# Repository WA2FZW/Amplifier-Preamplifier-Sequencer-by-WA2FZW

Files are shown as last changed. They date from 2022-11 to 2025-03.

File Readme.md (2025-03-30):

Amplifier/Preamplifier/SDR Switch Sequencer Version 2.0
By: John Price – WA2FZW - March 30, 2025

This is a software controlled sequencer designed to be able
to control two low-noise mast-mounted preamplifiers, linear
amplifiers and SDR switching devices when used with the
Icom IC-9700 on any two of the three bands that radio can
operate on.

The timing of the sequencing is controlled by the software
in an Arduino Nano.

Version 2.0 is an improvement over previous versions in
that the sequencing can be initiated via a DTR or RTS
signal from an optional USB to TTL interface. The
sequencing can also be initiated via an optional footswitch.
This has the advantage of being able to put the radio
into transmit mode after the preamps and amplifiers have
been switched.

The documentation, software and Gerber files to make the
version 1.4 PCBs are still available here. That version
is designed for use with my Yaesu FT-891.

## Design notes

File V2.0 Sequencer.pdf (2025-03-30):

- Page 1 -

## IC-9700 Amplifier/Preamp Sequencer Version 2.0 © John Price – WA2FZW - March, 2025

## Table of Contents

- Page 2 -

- Page 3 -

## Introduction

This document describes a sequencer used to switch one or two linear amplifiers, antenna mounted receive preamplifiers and switch boxes that allow receiving on an SDR when the radio status changes from transmit to receive and vice-versa.

Version 1.0 of the device was specifically designed to work with the Yaesu FT-891. (https://www.yaesu.com/indexVS.cfm?cmd=DisplayProducts&ProdCatID=102&encProdID=DF4DB262968932E999EAF928B5B6A1A7)

In Version 1.4 I added the capability to key one or the other of two amplifiers, but it only supported one preamp and one SDR switch box. Version 1.5 supports two of everything, but eliminates the transmit inhibit capability used in the unit for the Yaesu FT-891.

Version 1.5 is designed specifically for the Icom IC-9700 (https://www.icomamerica.com/en/products/amateur/hf/9700/default.aspx) on any 2 of the 3 bands it can operate on. In my case, I’m only operating on 2 meters and 70 centimeters and thus you’ll see that the panel labels on my unit reflect that.

Version 2.0 improves the design when being used for the digital modes. By adding an optional USB to TTL converter, (https://modulshop.hu/custom/modulshop/image/data/srattached/32e90db4e053c6b6411c2638c8aaf046_6in2-cp2102.pdf) WSJT-X can be told to use that to initiate the sequence via the RTS (Request to Send) signal instead of CAT (CI-V) control. The sequencer will switch the preamp followed by the amplifier and finally the radio itself; this accomplishes the same thing as the Yaesu’s transmit inhibit did in the original design. You could also use DTR (Data Terminal Ready) to accomplish the same thing.

When operating SSB or CW, you can use an optional footswitch to trigger the sequencer which works like the RTS signal in that the radio will be keyed last.

If neither the USB to TTL converter or footswitch is installed, the sequencer will work like previous versions; triggered by keying the radio’s microphone, transmit button or CAT control. Do not try to operate break-in CW or use VOX control under any circumstances when using the sequencer this way.

- Page 4 -

## The Hardware

Some Assumptions

- If installed, the RTS line on the USB to TTL converter is normally at 5V and goes to ground when RTS is activated.
- The radio has a PTT line (SEND in IC-9700 nomenclature) that goes to ground when the radio is put into transmit mode either manually or via CAT control.
- The sequencer can key the radio by grounding its PTT (SEND) line (indirectly via the TX_KEY GPIO pin and K4) when the sequencer is activated via the RTS line.
- The preamplifiers are put in receive mode by powering them from a +12V source. Removing the +12V power switches them to transmit (bypass) mode (fail-safe operation).
- The SDR switch boxes are switched from receive mode to transmit mode by grounding a PTT input on the switcher. SW4 and SW5 on the schematic are optional switches to ground the PTT line of the SDR switchers to put one or both into permanent transmit (bypass) mode.
- The linear amplifiers are keyed by grounding their keying inputs. Relay contacts are used for this so the amplifier’s keying voltage can be pretty much anything. A SPDT switch (SW6) selects which of the two amplifiers is actually keyed. I used a center-off switch which allows neither amplifier to be keyed.
- This sequencer is designed primarily to be used when running the various digital modes.
- J8 connects to an optional RCA jack which is for a footswitch. The footswitch acts like the RTS signal and provides a fail-safe method of operating for SSB and CW.

The use of the USB to TTL converter is optional. If not used, the digital mode programs can still trigger the sequence via CAT commands as in previous versions of the sequencer. If you don’t use the USB to TTL converter, K5 does not need to be installed.

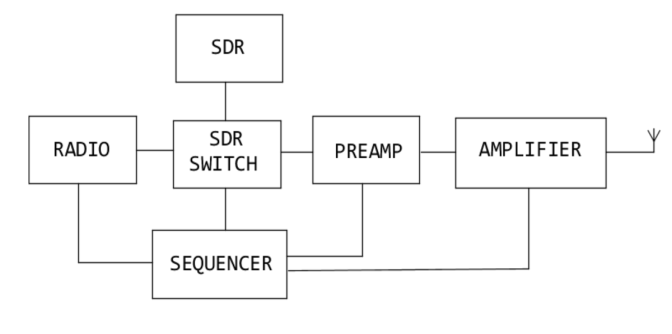
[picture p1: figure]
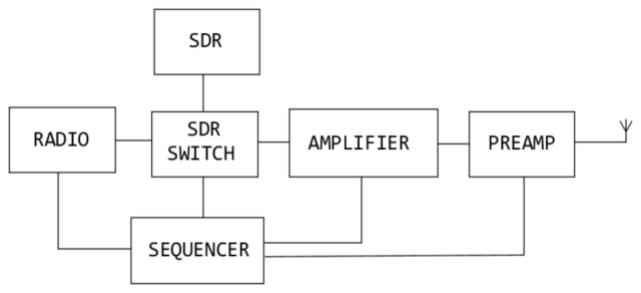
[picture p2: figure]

- Page 5 -

Equipment Configurations

There are two possible configurations one might use when using an external preamplifier, linear amplifier and/or SDR switch:

Configuration 1 | Configuration 2

The primary difference is whether the preamp is ahead of or behind the amplifier. If you have preamplifiers that can handle the output power of the amplifier, it’s better to put them between the antenna and the amplifier and as close to the antennas as possible.

Any of the major components (except the radio and antenna) are optional. If all you have is a radio and an antenna, you can stop reading because you have no need for this sequencer!

Which configuration you have and what specific equipment will determine how to set the various delay values in the software.

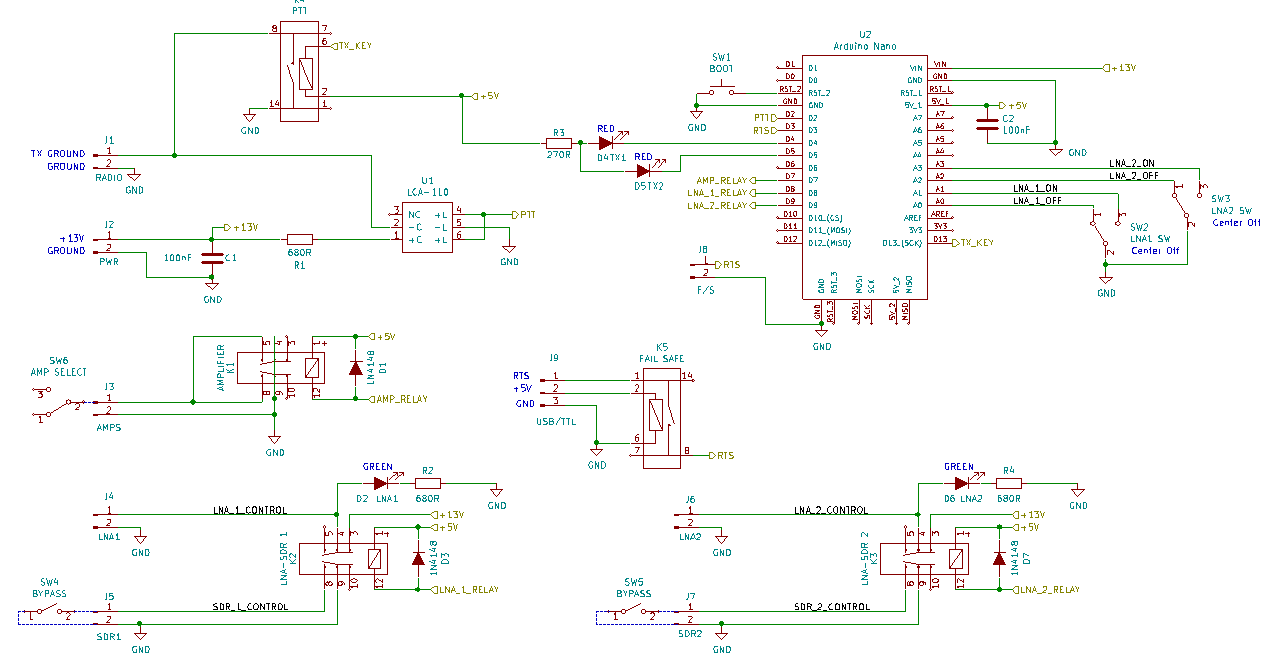
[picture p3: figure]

- Page 6 -

Theory of Operation

Here’s the schematic:

Switches SW4, SW5 and SW6 are optional.

Note that although the schematic shows the +13V power source as being from the radio, I power mine from the same 12V power supply that powers the radio. The IC-9700 is capable of 1 amp from the ACC connector and I would be pushing that limit with the relays in the 2 LNAs and the SDR switchers in my configuration. I ran the original version of the sequencer from the radio’s power when there was only one preamp being switched with no problems.

When the various pieces of equipment are switched between receive and transmit mode is controlled by the software in the Arduino Nano processor. We’ll get to setting the timing later.

In Version 2.0, the receive to transmit sequence can be initiated in three ways. When using WSJT-X (or any of the other digital mode programs), the sequence is initiated via a RTS signal provided from an optional USB to TTL converter. (https://modulshop.hu/custom/modulshop/image/data/srattached/32e90db4e053c6b6411c2638c8aaf046_6in2-cp2102.pdf) The link is for the particular one I used; I suspect there others which will work just as well.

- Page 7 -

When the RTS input goes LOW, the processor immediately switches the preamps and SDRs to the transmit mode via K2 and K3. After LNA_ON_DLY milliseconds, the selected amplifier is keyed via K1. Then after PTT_ON_DELAY milliseconds, the TX_KEY GPIO pin is set to TX_ON which will put the radio itself into transmit mode by activating the radio’s PTT line via K4 on the schematic.

The sequence can also be initiated when the radio’s PTT line goes active; this will be the case when the radio is sent a transmit command via CAT control or the operator keys the microphone. This is indicated by the radio’s PTT input going to ground. That causes a LOW indication on the PTT output of U1 on the schematic.

When the transmit sequence is started via the radio’s PTT line, the process is the same except we do not re-key the radio via the TX_KEY GPIO pin. Be very careful when keying the transmitter manually as it is very easy to destroy the preamp and/or SDR. It is much safer to use the optional footswitch for SSB or CW.

The transmit to receive sequence is also a bit different in Version
2.0. There is the (remote) possibility that while the radio was initially put into the transmit mode via the RTS signal, the operator also manually keyed the radio. The process will be explained in the description of the SetReceive function below.

Preamp Always On or Off Switch Considerations

Two switches (SW4 and SW5) were added in a previous version of the hardware when I started using the IC-9700 for satellite work. When working the satellites, the radio is transmitting on the 70cm band and receiving on 2 meters (or vice-versa). Without the switches, when transmitting on 70cm and listening on 2 meters, the 2 meter preamp would switch off when I transmitted causing me to sometimes no longer be able to hear myself.

Putting the switch for the receive band in the ‘ON’ position cured the problem.

VERY IMPORTANT: Be very careful when switching back to normal operations to put the switch back to the normal operating position or to the ‘OFF’ position. I already fried one rather expensive preamp!

- Page 8 -

When one (or both) of the switches is in the ‘ON’ position the red transmit indicator LED for that band will flash rapidly as an alert when the radio’s PTT is not active. When the PTT goes active, however, both red LEDs will be on continuously.

Also when the switch is in the ‘ON’ position, the SDR switch will be stuck in receive mode. You can put them into permanent transmit mode by powering them off or putting the (optional) SDR Disable switches (SW1 and SW2) into the ‘DISABLE’ position. Of course you won’t be able to receive on the SDR in this mode.

My SDR switcher (https://github.com/WA2FZW/SDR-Splitter-Switcher-by-WA2FZW) also has its own bypass switch.

K5 is a fail-safe relay. I found in testing the initial prototype that when the USB connection to the USB to TTL converter was disconnected, the RTS signal went to a LOW (active) state which caused everything to switch to transmit mode. The same thing would happen when rebooting the PC.

If the 5V output from the USB to TTL converter goes away, K5 disconnects the RTS line from the processor. The Arduino’s internal pullup resistor on GPIO pin D3 keeps the RTS signal showing as inactive. The footswitch (also connected to D3) will continue to be functional.

The Printed Circuit Board

The hardware consists of a printed circuit board (PCB) containing an Arduino Nano (https://www.arduino.cc/en/pmwiki.php?n=Main/ArduinoBoardNano) (or clone) processor, five mechanical relays, (https://www.jameco.com/webapp/wcs/stores/servlet/ProductDisplay?catalogId=10001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) one solid state relay (SSR), a few resistors, a couple of capacitors and several LEDs and switches (mounted externally).

The board can be powered from the radio if it can conveniently provide 12 to 13 volts and enough amperage however one must be careful not to exceed any current limitations the radio might have (1 amp max for the IC-9700). I powered earlier versions of the sequencer (with a single preamp and no SDR switcher) from the radio with no problems but now use a separate power supply (A wall-wart is fine if it doesn’t make RFI). I use the same power supply that powers the radio.

U1 is an LCA-110 solid state relay (SSR) which provides isolation between the radio’s PTT line and the processor. It is required as the normal voltage on the PTT line is more than the 5V that the Arduino pins can handle. I measured a bit over 6V on my IC-9700; it may be higher for other radios.

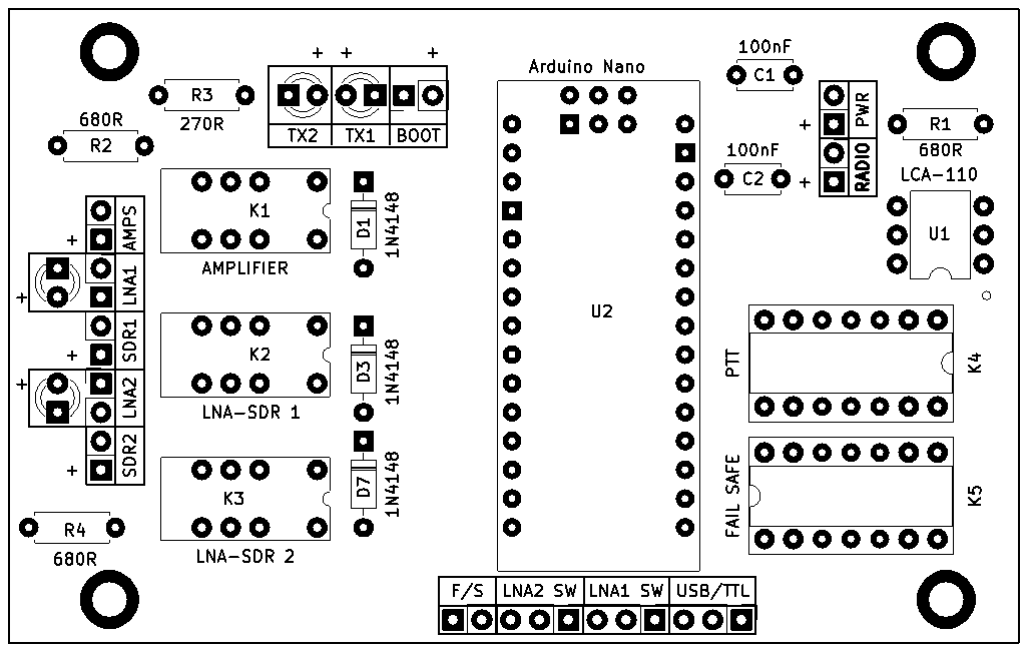
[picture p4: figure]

- Page 9 -

Relay K1 keys the amplifier(s). Relays K2 and K3 provide power to the preamps and ground the PTT inputs on the SDR switches in transmit mode. K4 grounds the radio’s PTT line when the sequence is initiated via the RTS signal

The LEDs indicate when the radio’s PTT line is active (red), and when the preamp is in receive mode (green). The preamp LED is operated by the relay which supplies power to the preamp in receive mode providing a positive indication that power is actually being sent to the preamp (or at least to the connector on the rear panel).

SW4 and SW5 are connected to the PCB. The optional switches to disable the SDRs (SW1 and SW2) are not connected to the PCB, but are simply SPST switches that ground the PTT lines to the SDR switchers. I simply connected them across the RCA jacks for the SDR switchers.

The SPDT switch (SW6) to select which amplifier should be keyed is connected between J3 (AMPS) and the RCA jacks for the amplifier keying lines.

Here’s what the printed circuit board layout looks like:

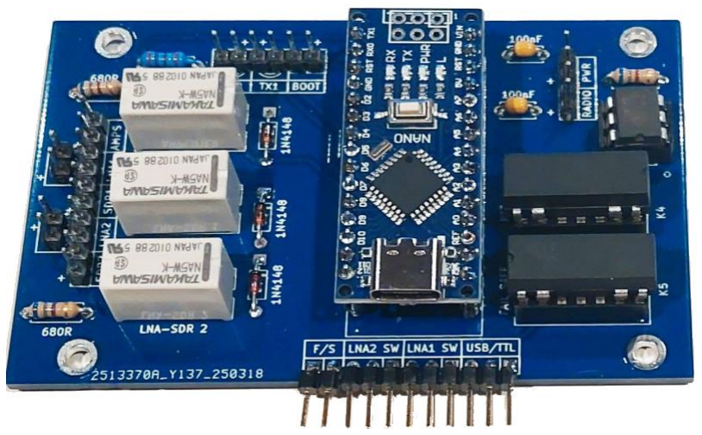
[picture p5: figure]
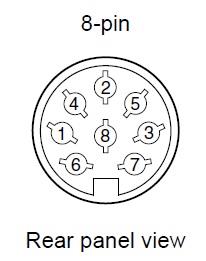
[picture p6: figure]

- Page 10 -

And here’s the assembled circuit board:

Icom IC-9700 Connections

The Icom uses a large size 8 pin DIN connector (ACC) for the external connections:

I have a couple versions of the IC-9700 Basic Operating Manual, (https://www.icomjapan.com/support/manual/2156/) however they all have the same description of the pins on the ACC DIN connector. On the original version for the IC-9700, I cut one end off of a DIN cable and hardwired the cable to the PCB; this time I used a DIN jack on the rear panel of the sequencer. The DIN Cable I used to make the connection came from Amazon. (https://www.amazon.com/dp/B0794WSGN9?ref=ppx_yo2_dt_b_product_details&th=1)

- Page 11 -

The following table gives the pin usage I used to connect the radio to the sequencer (I used an external power source instead of the 13.8V from the radio as it is only capable of supplying 1 amp):

Pin | IC-9700 Nomenclature
2 | Ground
3 | Send (aka PTT)
7 | +13.8V @ 1 Amp

The Icom manual says the SEND line is both an input and an output (I verified this). When the radio is keyed via the microphone’s PTT button, the TRANSMIT button on the front panel or via CI-V control, the SEND line goes LOW.

Putting a LOW on the SEND line will also cause the radio to go into transmit mode.

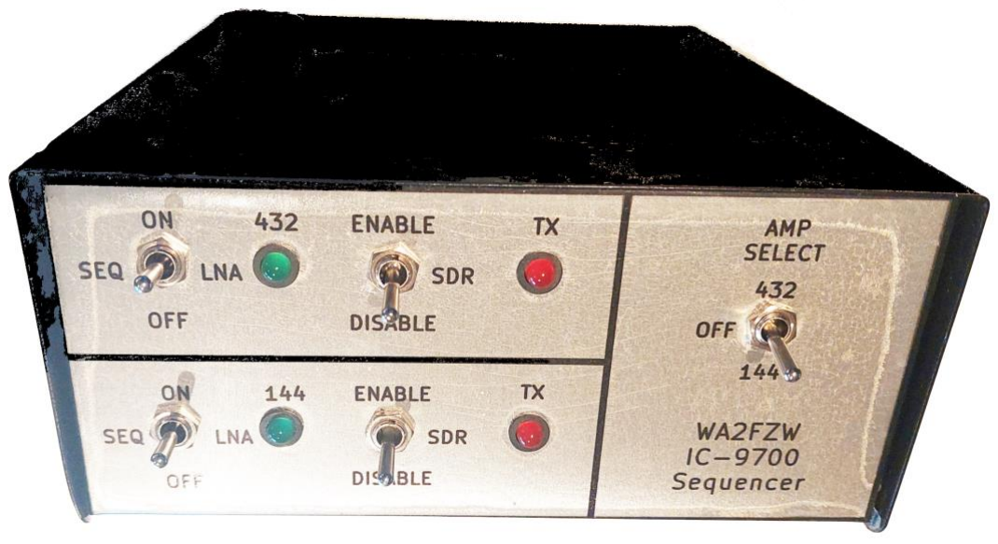
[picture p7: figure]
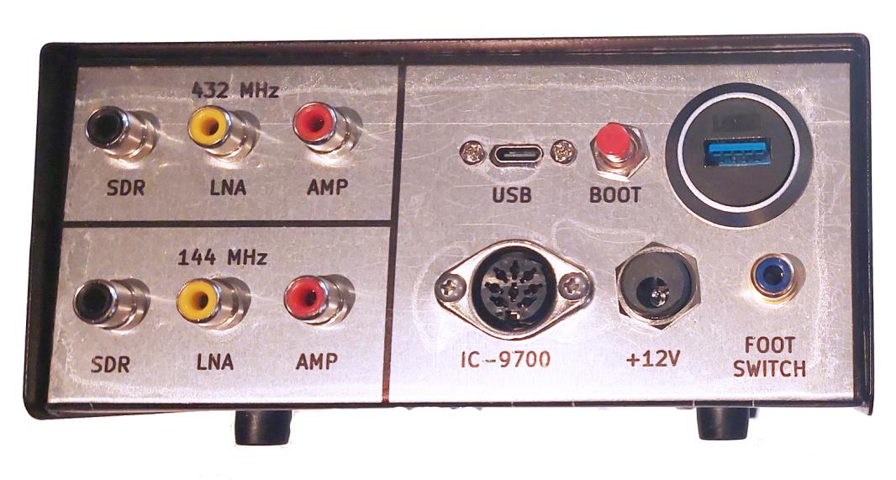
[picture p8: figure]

- Page 12 -

Some Construction Notes

I built the unit into an enclosure from Circuit Specialists. (https://www.circuitspecialists.com/metal-instrument-enclosure-e-3) Here’s what the final assembly looks like (sorry, not the greatest pictures):

- Page 13 -

## The Software

GPIO Pin and Other Symbols Defined

The following are the GPIO pin assignments; for the most part, the symbols used match the net names on the schematic:

PTT | 2 | PTT Indication (interrupt capable)
RTS | 3 | RTS Indication (interrupt capable)
TX1_LED | 4 | Band #1 transmit indicator LED
TX2_LED | 5 | Band #2 transmit indicator LED
AMP_RELAY | 7 | Operates the linear amplifier relay (K2)
LNA1_RELAY 8 | Operates the band #1 preamp/SDR relay (K3)
LNA1_RELAY 9 | Operates the band #2 preamp/SDR relay (K4)
TX_KEY | 13 | Operates K1 to ground the PTT line
LNA1_OFF | A0 | Preamp for band 1 always off when LOW
LNA1_ON | A1 | Preamp for band 1 always on when LOW
LNA2_OFF | A2 | Preamp for band 2 always off when LOW
LNA2_ON | A3 | Preamp for band 2 always on when LOW

The DEBUG symbol can be defined as 0, 1 or 2. When set to 0, no debugging stuff is enabled. Setting DEBUG to 1 causes various status messages to be sent to the Arduino IDE’s serial monitor. Setting the value to 2 also exaggerates the sequence timing values to facilitate monitoring with meters and/or an oscilloscope for testing.

There are several definitions of states for the various GPIO pins to make the pin states more readable, for example:

AMP_ON | LOW | // A LOW on the AMP_RELAY pin keys the linear
AMP_OFF HIGH

There are several global variables:

txState | | Current transmit/receive state
oldTxState | Previous transmit/receive state
rtsState | | Current state of the RTS line
pttState | | Current state of the PTT line
lna_1_ForcedOff true when switch SW2 is in the always off
| | position
lna_1_ForcedOn | true when switch SW2 is in the always on position
lna_2_ForcedOff true when switch SW3 is in the always off
| | position

- Page 14 -
lna_2_ForcedOn | true when switch SW3 is in the always on position
tx_1_LedState | Used in CheckBlink to toggle the LED state
tx_2_LedState | Used in CheckBlink to toggle the LED state

Timing Settings

There are four symbols in the software that define the timing for the sequencer:

LNA_ON_DELAY | 25mS Time between switching the LNA(s) to transmit mode and keying the amplifier
PTT_ON_DELAY | 50ms Time between keying the amplifier and keying the radio when the sequence is initiated via the RTS signal.
PTT_OFF_DELAY | 10mS Used in the SetReceive function when it is determined that the PTT line is active because of K4 being energized.
AMP_OFF_DLY | 50mS Delay between turning the amplifier(s) off and returning the preamp and SDR switch to receive mode.

The values shown are those currently set in the software when the DEBUG level is 0 or 1. The values may be adjusted to suit your needs based on the specifications of your particular equipment and the equipment configuration. There are alternate settings that are used when the DEBUG level is set to 2; I currently have all except PTT_OFF_DELAY set to 3 seconds.

Note, the sequencer is designed primarily for digital mode operations. It can be used for SSB operations using manual PTT (not VOX) and pause slightly between keying the radio and speaking. Using it for CW operation should only be done if the radio is put into transmit manually before operating the CW key; in other words don’t try using break-in modes (I fried a $250 LNA that way)! You can also use a footswitch to trigger the transmit sequence. Using the footswitch is the same as triggering the transmit sequence via the RTS line which will cause the preamps and linear to be switched before the radio.

- Page 15 -

Overall Functionality

The software is pretty trivial. The setup function sets up all the GPIO pins used and sets them to the proper initial states.

Experimentation has shown that the preamp and amplifier relays will not operate until their GPIO pins are set as OUTPUT pins, thus the preamp will startup in transmit (bypass) mode and the amplifier will be off. Note, however that during the reboot process, the radio gets keyed for a few milliseconds, so when rebooting, make sure the preamps and linears are disabled.

The first thing done in setup is to make sure the radio is not in transmit mode unless the operator has it keyed manually; the sequencer cannot do anything about that.

The loop function really only does a few things; it first calls the CheckBlink function which blinks one or both of the transmit LEDs when one or both of the LNAs are in the always on mode.

Next, the SwitchPreamp function is called every 50 milliseconds which may or may not switch the preamps and SDR switches into receive mode. I’ll explain that function in more detail momentarily. It is called everytime through the loop so it can detect whether or not one of the LNA switch settings changed.

Next, the loop function looks at the states of the PTT and RTS lines to see if the transmit/receive status needs to be changed and if so, invokes the SetTransmit or SetReceive to take the appropriate action. Note that the optional footswitch works like the RTS signal.

The SetTransmit Function

This function takes care of switching things from receive mode to transmit mode.

First the preamps and SDR switchers are switched to transmit mode (unless one or both of the preamps are in the always on mode).

After delaying for LNA_ON_DLY milliseconds, the amplifier is keyed; if SW6 is installed, the operator can select which of two amplifiers is keyed.

- Page 16 -

There are two ways in which the transmit sequence could have been initiated. If it was started because the PTT went active, there is nothing else to do except set the txState and oldTxState variables to TX_ON.

However if the sequence was started because the RTS went active, we need to activate the PTT line to actually put the radio into transmit mode. That is done PTT_DELAY milliseconds after the amplifier is keyed.

The SetReceive Function

This function handles the transmit to receive sequencing. It is a bit trickier than in previous versions due to the two different methods of putting everything into transmit mode.

First of all, we check the RTS status; if it is active, we leave everything in transmit mode and simply return from the function.

If RTS is not active, we check to see if the PTT is active. If it is active, it could be because the radio was keyed manually or because the software activated it via K4. We assume it’s active via K4 so we attempt to turn the PTT off and wait up to PTT_OFF_DELAY milliseconds. After waiting, we check to see whether or not the PTT is still active. If it is, the assumption is that the radio was keyed manually or via a CAT command and not via the RTS line. If this is the case, we leave everything in transmit mode and return.

If the PTT is now inactive, we start the transmit to receive sequence. The transmit LEDs are turned off and the amplifier is unkeyed. After LNA_ON_DLY milliseconds, the preamps and SDR switchers are switched back to receive mode unless one or both switches are in the ‘OFF’ position.

The CheckBlink Function

This function checks the status of the preamp mode switches and if one or both is on, it flashes the transmit LED for the associated band every 100 milliseconds to alert the operator to be very very careful.

There is a 2 millisecond delay at the end of the function. That ensures that the next time the function is called the system time won’t be on the same 100 millisecond increment.

- Page 17 -

The PTT_ISR and RTS_ISR Functions

These are invoked via software interrupts whenever the state of the PTT or RTS lines changes. Both simply set the state of the input by reading the GPIO pin, however if the RTS is already active, PTT interrupts are ignored. This is because the software turns the PTT on when the sequence is started by RTS going active, which also generates an interrupt.

The SwitchPreamp Function

This function perhaps deserves a bit more explanation than the other functions. It takes two arguments; the first being which band(s) should be switched (BAND_1, BAND_2 or BOTH_BANDS). The second argument is the new preamp and SDR switch state requested (LNA_RX or LNA_TX).

When the argument is LNA_TX, the selected preamp(s) and SDR switch(es) will always be put into transmit (bypass) mode unless the associated LNA switch (SW2 and/or SW3) is in the ‘ON’ position. If the switch is in the ‘ON’ position, both the preamp and SDR switch will remain in receive mode (BE VERY CAREFUL).

However, if the argument is LNA_RX, the preamp(s) and SDR switch(es) will only be switched into receive (active) mode if the associated preamp enable switch is in the ‘SEQ’ position and the PTT is not currently active (TX_OFF).

The Test_LNA Function

You will see a call to this function commented out at the end of the setup function. When the function call is un-commented, it will be invoked. It allows testing of the preamp switch functions. It is a never-ending loop, so when it runs, none of the rest of the sequencer functions will be enabled.

When one of the ‘LNA’ switches is put in the ‘ON’ position, the associated LNA LED will flash. When the switch is in the ‘OFF’ position, the associated LED should go out. The LED should also remain on when the switch is in the ‘SEQ’ position.

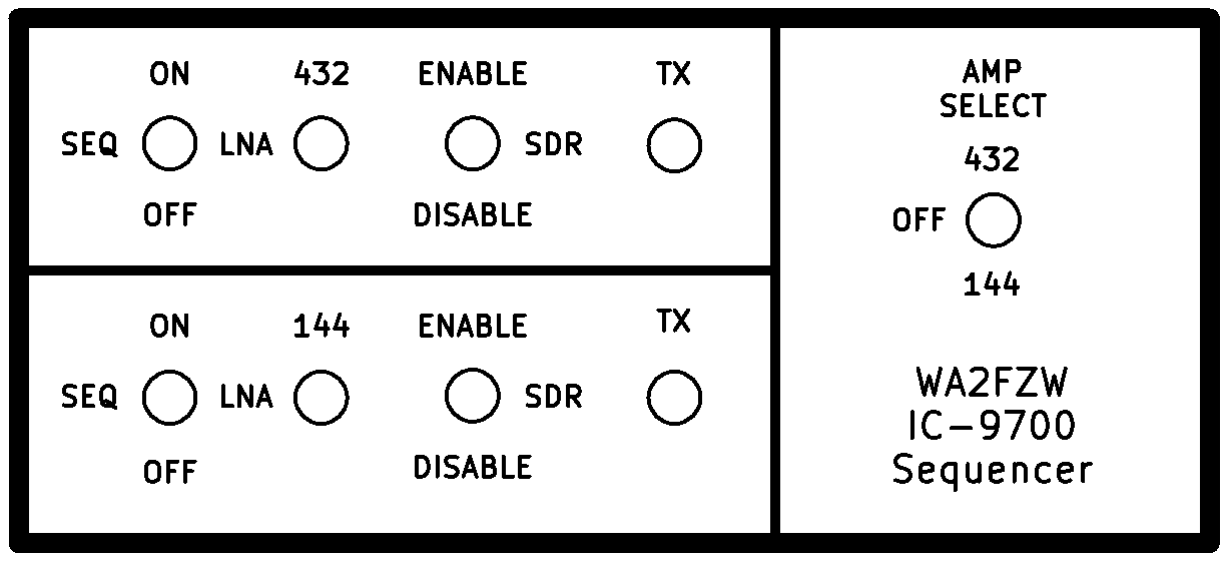
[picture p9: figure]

- Page 18 -

You should also see the voltage on the associated ‘LNA’ connectors (if the unit is connected to a 12V power source) following the LED and you should also see contact closure/opening following on the ‘SDR’ connectors provided the associated ‘SDR’ switch is in the ‘ENABLED’ position.

If the ‘SDR’ switch is in in the ‘DISABLED’ position you should see a constant contact closure on the associated ‘SDR’ connector.

It is critical to test everything before actually hooking the sequencer up to external equipment as you can easily destroy a preamp or SDR. The complete testing procedure is documented below.

The ShowPinStatus Function

When the DEBUG level is set to ‘1’ or more, this function reports the status of the LNA switches, the PTT line and the RTS line at startup.

## Some Operational Notes

Front Panel Controls and Indicators

Here’s what the front panel looks like:

In the two areas on the left, from left to right are:

- LNA/SDR ‘ON’, ‘SEQ’, ‘OFF’ switches (SW2 & SW3 on the schematic).
- Green preamp power on (receive mode) LEDs.

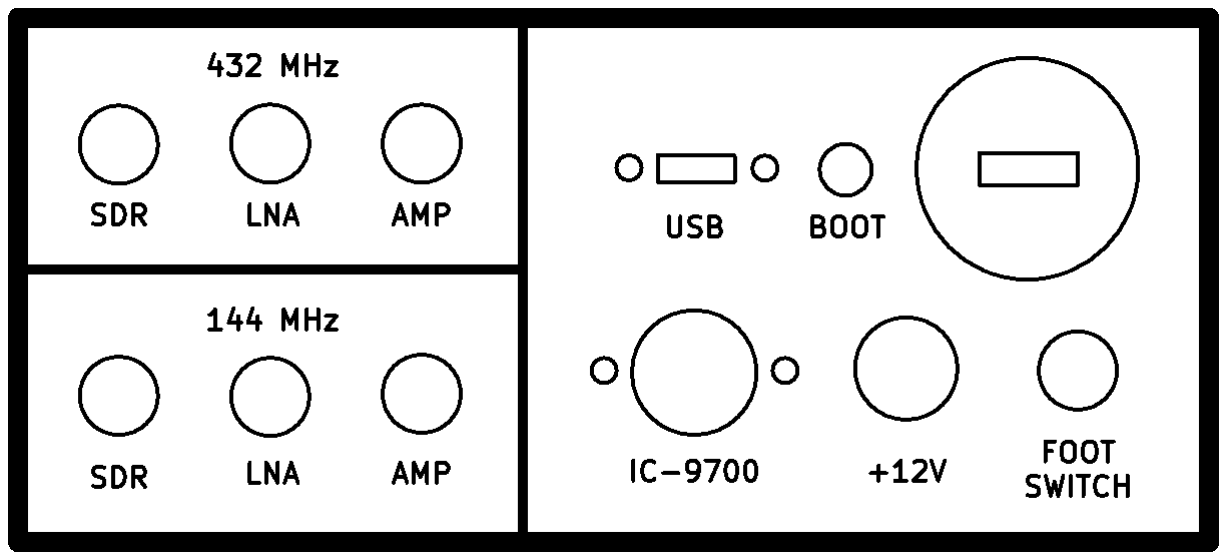
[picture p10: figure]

- Page 19 -
- SDR ‘ENABLE’/’DISABLE’ switches (SW4 and SW5).
- Red transmit indicator LEDs.

In my build, the top section (labeled 432) are the BAND 2 items and the bottom section (labeled 144) are the BAND 1 items.

The section on the right side contains the amplifier select switch (SW6). I used the center-off option so that both amplifiers can be disabled.

Rear Panel Connections

Here’s what my rear panel looks like:

In the sections to the left are the connectors for the SDR switchers, preamps and amplifiers. I used RCA jacks. As on the front panel, the top part (labeled 432 MHz) are the connections for BAND 2 and the bottom section (labeled 144 MHz) is for the BAND 1 connections.

The section to the right contains:

- A type ‘C’ USB connector which allows one to re-program the unit without having to take it apart.
- The ‘BOOT’ momentary pushbutton (SW1 on the schematic).
- A type ‘A’ USB connector which is the USB connection for the USB to TTL converter used to generate the RTS signal.
- The 8-pin DIN jack for the connection to the IC-9700.

- Page 20 -
- The 12V power connector.
- An RCA jack for the footswitch.

The type ‘A’ USB connector is actually a panel mounted type ‘A’ to ‘A’ USB connector. The USB to TTL converter plugs into the rear of the unit. It came from Amazon. (https://www.amazon.com/dp/B09VGK59XQ?ref=ppx_yo2ov_dt_b_fed_asin_title&th=1)

SDR ENABLE/DISABLE Switches

If you are using an SDR switcher and have installed the switch to disable the SDR switcher as described above it is best to disable the SDR when not actually using it. If you’re using my switcher or a different one with a splitter, there is a 3dB loss due to the splitter.

There are several such switchers available. The one I am using is of my own design. (https://github.com/WA2FZW/SDR-Splitter-Switcher-by-WA2FZW) It has an internal splitter and grounds the input to the SDR in transmit mode.

Another good one is from Paul (N2EME). (https://sdrswitch.com/) Unlike mine, Paul’s requires an external splitter to be able to receive simultaneously on the radio and the SDR.

There is a switcher available somewhere on Amazon and MFJ also has one (although they’re out of business, their stuff seems to still be available). Paul and I have tested these and they are not very good; I don’t recommend using wither one.

LED Indications

Green LEDs – On indicates power is being supplied to the preamp for that band (or at least to the connector on the unit), which means it is in receive mode. If the LED is off, the preamp is in transmit (bypass) mode.

- Page 21 -

Red LEDs – Both on indicates the radio’s PTT is active either because the radio was keyed manually or via a CAT command or as a result of the transmit sequence being activated via the RTS line or a footswitch. Flashing is a warning that the preamp switch for the band is in the always ‘ON’ mode and transmitting on that band could damage the preamp. This feature is primarily for the IC-9700 where in satellite mode, you are transmitting on one band and receiving on a different band; each band on the IC-9700 has its own antenna feed.

Note that putting one of the preamp switches into the ‘ON’ position will also put the associated SDR switch into permanent receive mode and transmitting could destroy the SDR. Whenever the preamp switch is in ‘ON’ you should ‘DISABLE’ the SDR switcher.

Preamp Overload Protection

Both my preamps contain circuitry to protect them from strong nearby signals (in-band or out-of-band). If you use a preamp without such protection, it is important that the ‘ENABLE’/’DISABLE’ switch be used to put yours into bypass mode before using a different nearby transmitter and/or antenna. I do this even though my preamp has the protection circuit.

## Testing

I strongly suggest testing everything without any amplifiers, preamps or SDRs connected to the unit. It is ok to connect the unit to the radio for testing, or you could use a jumper wire to simulate the radio’s PTT. The unit would have to be connected to a 12V source. The only test equipment needed is a volt/ohm meter.

Preamp ‘ON’/’OFF’/’SEQ’ Switches (SW2 & SW3)

With power applied to the unit and these switches in the ‘SEQ’ position, both green LEDs should be lit and you should measure +12V on the LNA connectors (if the PTT is not active). The SDR connectors should show an open condition.

- Page 22 -

With the radio’s PTT active, and these switches are in the ‘SEQ’ position, the green LEDs should go out there should be no voltage on the ‘LNA’ connectors. The ‘SDR’ connections should show a contact closure.

Moving the switches to the ‘OFF’ position should cause the green LEDs to go out and there should be no voltage on the ‘LNA’ connectors regardless of the PTT state. The ‘SDR’ connections should show a contact closure.

With the switches to the ‘ON’ position (PTT inactive) the green LEDs sill be illuminated and there should be +12V on the ‘LNA’ connectors. The red LEDs should be flashing. The ‘LNA’ connections should show an open condition.

The Test_LNA function call at the end of the setup function in the software can be enabled to facilitate testing the ‘LNA’ switches.

SDR ‘ENABLE’/’DISABLE’ Switches

With these switches in the ‘DISABLE’ position, the SDR connectors should show a contact closure regardless of the state of the preamp switches or the radio’s PTT.

When these switches are in the ‘ENABLE’ position, the SDR connections should show open when the PTT is inactive and should show a contact closure when the PTT is active.

If you implemented the option to have the preamp switches also disable the SDRs when in the ‘ON’ position (as mentioned above), the SDR connections should show a contact closure when the preamp switches are in the ‘ON’ position.

PTT Tests

With the preamp switches in the ‘SEQ’ position and the SDR switches in the ‘ENABLE’ position, the green LEDs should be on and the red LEDs should be off when the radio’s PTT is inactive. There should be +12V on the ‘LNA’ connectors and open conditions on the ‘SDR’ connections.

- Page 23 -

With the switches still set as above, when the PTT is active, the green LEDs should go out and both red LEDs should light. There should be no voltage on the preamp connectors and the SDR connectors should indicate a contact closure.

One thing to be aware of; if one of the preamp switches is in the ‘ON’ position, the associated red LED should be flashing when the PTT is inactive. When the PTT goes active, however both red LEDs will be lit continuously.

With the PTT inactive the amplifier connections for both amplifiers should show an open condition. When the PTT goes active, the connection for the selected amplifier should show a contact closure. Make sure to check this for both amplifiers. As mentioned earlier, one could use a center-off SPDT switch so that neither amplifier is keyed.

DEBUG Output

Setting the DEBUG symbol to a value of 1 (or higher) causes several messages to be sent to the Arduino IDE’s serial monitor.

When the program is started, you will see the following messages showing the states of the LNA switches and the RTS and PTT lines:

WA2FZW - Amplifier/Preamp Sequencer - Version 2.0
LNA 1 Status = Always On
LNA 2 Status = Sequenced
RTS Status = Inactive
PTT Status = Inactive

When the sequence is initiated via the RTS or PTT line going active you will see a sequence of messages like the following. In this case, the sequence was initiated via the RTS line. The numbers are the readings from the millis() function at the time of the event and the text at the right are comments which are not part of the output:

Time: 4145 | Time sequence was initiated
pttState = 1 | PTT is inactive
rtsState = 0 | RTS is active
LNAs in TX: 4146 | LNAs switched to TX mode 1mS after RTS active
Amp On 4170 | Amp keyed 24 mS later
PTT On 4220 | PTT activated via K4 50mS later

- Page 24 -

When the RTS line was released, the following messages were produced:

Time: 7458 | Time RTS released
pttState = 1 | PTT is actually active (see note below)
rtsState = 1 | RTS is inactive
PTT Off 7460 | PTT released 2mS after sequence start
Amp Off 7510 | Amp un-keyed 50mS later
LNAs in RX: 7535 | LNAs switched to RX 25mS later

If DEBUG is set to 2 or higher, the times are exaggerated to facilitate watching the actual outputs with a meter or scope.

When the sequence was initiated via the RTS line, we do not show the PTT as being active. Doing so caused a lockup condition where the PTT wouldn’t be released when RTS went inactive.

## Known Bugs and Glitches

Booting the Processor

When the processor is booted, the various relays switch themselves into the proper receive mode, but very briefly switch to transmit mode. There is nothing that can be done about it as that’s just how the Arduino GPIO pins work. When initializing them

Because the radio will very briefly (milliseconds) be put into transmit mode, one should disable the preamps and amplifiers using the front panel switches when rebooting the processor.

## Possible Enhancements

The one thing I thought of (after having the PCBs made) would be to use a DPDT (not center off) switch for the amplifier selection and having the other side of the switch connected to a couple of GPIO pins (similar to how the preamp switches work) to tell the processor which band is being used for transmit.

With such a modification the transmit LEDs could actually show which band is in transmit mode rather than both of them being lit during transmit on either band. The software modifications would be fairly simple.

- Page 25 -

## Suggestion Box

I welcome any suggestions for further improvements. Please feel free to email me at WA2FZW@ARRL.net.

- Page 26 -

## Bill of Materials

Here is a list of the parts you will need and in many cases, links to where you can get the less common parts.

There are hyperlinks to Mouser Electronics for some of the parts. Mouser has implemented a Captcha-like guard against robots. Thus, you can’t simply click on the links, but if you copy the links and paste them into your browser they work (at least they did when I wrote this).

There are also hyperlinks for some items available from Jameco Electronics. Jameco has recently instituted a $25 minimum order policy, so if you order from them, find some other stuff you need!

The PCB | | Gerber files are available on Github. (https://github.com/WA2FZW/Amplifier-Preamplifier-Sequencer-by-WA2FZW)
R1, R2 & R4 | 680R 1/4W
R3 | 270R 1/4W
C1, C2 | 100nF 50V
U1 | LCA-110 SSR | 6-pin DIP package; available from Mouser (https://www.mouser.com/ProductDetail/IXYS-Integrated-Circuits/LCA110?qs=AN9n7QNm0jJpFrXJ0Ydzyw%3D%3D) and other common suppliers
U2 | Arduino Nano | I used clones which are much cheaper than genuine Arduinos.
D1, D3 & D7 | 1N4148
D2, D4, D5 & D8 | General purpose LEDs – 20mA | Pick whatever colors you like. I used red for the TX indicators and green for the preamp indicators. The documentation assumes these colors. The PCB is designed so that the LEDs can be installed on the PCB or connected externally.
SW1 | Momentary push button

- Page 27 -
SW2 & SW3 | SPDT center off toggle switches
SW4 & SW5 | SPST Toggle Switch
SW6 | SPDT toggle switch | Not on the PCB, but connected between J3 (AMPS) and the amplifier connectors to select one of two amplifiers. A center-off switch can be used to select neither amplifier.
K1 – K3 | Fujitsu NA5W-K DPDT relay | Available from Jameco (https://www.jameco.com/z/NA5W-K-Fujitsu-5-Volt-178-Ohm-Double-Pole-Double-Throw-Relay_2202360.html)
K4 & K5 | NTE R56-1D.5-6 Reed Relay | I’m told NTE is going out of business. An equivalent is the Littelfuse HE721A0500; available from Mouser (https://www.mouser.com/ProductDetail/Littelfuse/HE721A0500?qs=X8LBAgEWIKJojdycp1Gg9A%3D%3D) or Digikey. (https://www.digikey.com/en/products/detail/littelfuse-inc/HE721A0500/133183)
J1 – J9 | Various size 2.45mm male pin headers | The PCB layout allows some of these to be installed as larger headers. Also, there are pin headers for SW1, SW2 & SW3. Use vertical headers except for the ones for SW2, SW3, J8 and J9 which need to be horizontal ones.
IC-9700 Connection | 8-pin large female DIN receptacle | Available from Jameco. (https://www.jameco.com/z/SD-80SN-JVP-Jameco-ValuePro-Standard-DIN-Socket-Female-8-Pin-Panel-Mount_15861.html) Connects to J1 and J2 if 13.8V from the radio is used to power the unit.
8-pin DIN cable | From IC-9700 to the sequencer | Available from Amazon (https://www.amazon.com/Traovien-Extension-Converter-Suitable-Televisions/dp/B0CCVH5LM7) and other places.
Power Connector | | Whatever you like. I used this one from Amazon. (https://www.amazon.com/Plastic-Panel-Mount-Power-Jack/dp/B004M4CUH6?th=1)
Amplifier, LNA, SDR Switch, etc. Connections | RCA and/or coaxial female receptacles | However many you need to connect all your equipment. Use whatever you like as connectors for the amplifier, preamp, SDR switch and power connectors.

- Page 28 -
USB to TTL converter | The one I used came from eBay. (https://www.ebay.com/itm/187036698579?_skw=cp2102+usb+to+ttl&itmmeta=01JPRY8SMMAQHQRM7N0FG9SKFJ) There are others available which should also work.
Penglin USB 3.0 Panel Mount USB Pass Through Connector | Available from Amazon. (https://www.amazon.com/dp/B09VGK59XQ?ref=ppx_yo2ov_dt_b_fed_asin_title&th=1)
Enclosure | I used one from Circuit Specialists; (https://www.circuitspecialists.com/metal-instrument-enclosure-e-3) 6.7” x 5.9” x 2.8”.

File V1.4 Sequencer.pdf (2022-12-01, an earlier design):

- Page 1 -

## Amplifier/Preamp Sequencer Version 1.4 John Price – WA2FZW

## Table of Contents

- Page

2

- Page 3 -

## Introduction

This document describes a sequencer used to switch one or two linear amplifiers, an antenna mounted receive preamplifier and a switch box that allows simultaneous receiving on an SDR when the radio status changes from transmit to receive and vice-versa.

Version 1.0 of the device was specifically designed to work with the Yaesu FT-891. (https://www.yaesu.com/indexVS.cfm?cmd=DisplayProducts&ProdCatID=102&encProdID=DF4DB262968932E999EAF928B5B6A1A7) This version will work with either the FT-891 (https://www.yaesu.com/indexVS.cfm?cmd=DisplayProducts&ProdCatID=102&encProdID=DF4DB262968932E999EAF928B5B6A1A7) or my Icom IC-9700. (https://www.icomamerica.com/en/products/amateur/hf/9700/default.aspx) The original version wouldn’t work when the Icom was being operated in satellite mode when transmitting on the 70cm band and receiving on 2 meters. When it transmitted on 70cm, the 2 meter preamp was being disabled. Since the whole idea of the full duplex operation is to be able to hear your own signal coming back from the satellite this was a problem!

Coming soon I will have both a 2 meter and a 70cm amplifier connected to the IC-9700, so the hardware was modified in Version 1.4 to provide the ability to key 2 amplifiers.

Also added in Version 1.4 is a provision to control an SDR switch that allows an SDR to be used as an alternate receiver.

The overall idea is to detect that the radio has been switched from receive mode to transmit mode and switch the preamplifier and SDR switch to transmit (bypass) mode before keying one of the linear amplifiers. When the radio is switched from transmit to receive the process is reversed.

## The Hardware

Some Assumptions

- The radio has a PTT line that goes to ground when the radio is put into transmit mode either manually or via CAT control.
- The preamplifier is put in receive mode by powering it from a +12V source. Removing the +12V power switches it to transmit mode (fail-safe operation).
- The SDR switcher is switched from receive mode to transmit mode by grounding a PTT input on the switcher. Not shown on the schematic is


- Page 4 -

an (optional) switch to ground the PTT line of the SDR switch to put it into permanent transmit (bypass) mode.
- The linear amplifiers are keyed by grounding their keying inputs. We use relay contacts for this so the amplifier’s keying voltage can be anything. You could also install a switch to select which of the 2 amplifiers should be keyed; I didn’t do this in my units however.
- This sequencer is designed primarily to be used when running the various digital modes. When used with the FT-891, it is fairly safe to operate SSB or CW, as the TX inhibit feature prevents RF output until everything has switched. This is not the case with other radios.

Equipment Configurations

There are two possible configurations one might use when using an external preamplifier, linear amplifier and/or SDR switch:

Configuration 1 | Configuration 2

The primary difference is whether the preamp is ahead of or behind the amplifier. If you have a preamplifier that can handle the output power of the amplifier, it’s better to put it between the antenna and the amplifier and as close to the antenna as possible.

Any of the major components (except the radio and antenna) are optional. If all you have is a radio and an antenna, you can stop reading because you have no need for this sequencer!

Which configuration you have and what specific equipment will determine how to set the various delay values in the software.

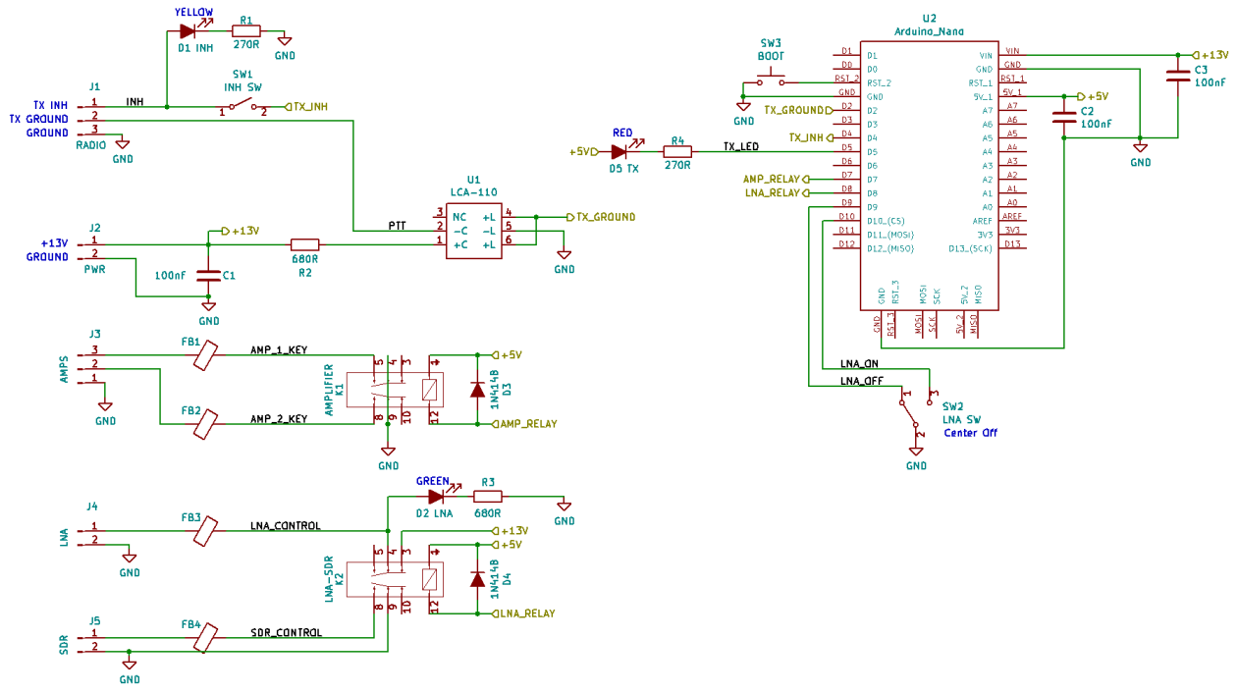
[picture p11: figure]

- Page 5 -

Theory of Operation

Here’s the schematic:

When the various pieces of equipment are switched between receive and transmit mode is controlled by the software in the Arduino Nano processor. We’ll get to setting the timing later.

The switching process begins when the radio’s PTT line goes active. We assume this is indicated by the PTT input going to ground. That causes U1 (LCA-110 solid state relay) to also put a LOW indication on the TX_GROUND output which will be seen by the processor almost immediately (interrupt enabled pin).

As soon as the processor sees the TX_GROUND go LOW, it immediately operates relay K2 which switches both the preamp and SDR switch to transmit mode unless switch SW2 is in the ‘Preamp Always On’ position; more on this later.

After a delay of LNA_ON_DLY milliseconds, relay K1 is operated which switches the amplifier(s) on. After another delay of AMP_ON_DLY milliseconds, the TX_INH pin is set to LOW which allows the FT-891 to actually produce power. The TX inhibit is a feature unique to the Yaesu radios and does not apply to other makes.

- Page 6 -

When the PTT line goes HIGH, the process is reversed. The TX_INH line is set to HIGH (again only applies to Yaesu radios) to stop any RF output and the amplifier(s) are turned off. After AMP_OFF_DLY milliseconds, the preamp and SDR switch are returned to the receive mode.

Preamp Always On or Off Switch Considerations

This switch was added in a previous version of the software when I started using the IC-9700 for satellite work. When working the satellites, the radio is transmitting on the 70cm band and receiving on 2 meters (or vice-versa). Without the switch, when transmitting on 70cm and listening on 2 meters, the LNA would switch off when I transmitted causing me to no longer be able to hear myself.

Putting the switch in the ‘Always On’ position cured the problem.

VERY IMPORTANT: Be very careful when switching back to normal operations to put the switch back to the normal operating position or to the ‘Always Off’ position. I already fried one rather expensive preamp!

When the switch is in the ‘Always On’ position the red transmit indicator LED will flash rapidly as an alert.

Also when the switch is in the ‘Always On’ position, the SDR switch will be stuck in receive mode. It should be put into permanent transmit mode by powering it off or putting the (optional) SDR Disable into the ‘Disable’ position. Of course you won’t be able to receive on the SDR in this mode.

The Printed Circuit Board

The hardware consists of a printed circuit board (PCB) containing an Arduino Nano (https://www.arduino.cc/en/pmwiki.php?n=Main/ArduinoBoardNano) (or clone) processor, a couple of relays, (https://www.jameco.com/webapp/wcs/stores/servlet/ProductDisplay?catalogId=10001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) a solid state relay (SSR), a few resistors and three LEDs.

The board can be powered from the radio if it can conveniently provide 12 to 13 volts and enough amperage; however one must be careful not to exceed any current limitations the radio might have. I have powered everything from both the FT-891 and the IC-9700 without any problems however I am now powering both my sequencers from an external 12 volt power supply.

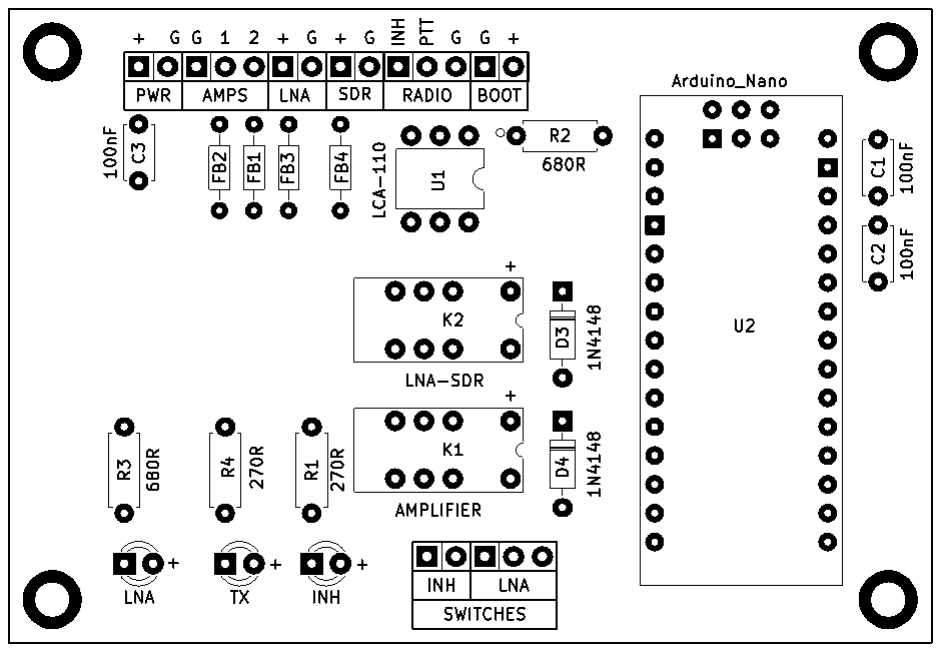
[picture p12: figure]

- Page 7 -

U1 is an LCA-110 solid state relay (SSR) which provides isolation between the radio’s PTT line and the processor. It is required as the normal voltage on the PTT line is 12V and the Arduino pins can only handle 5V.

Relay K1 keys the amplifier(s). Relay K2 provides power to the preamp and grounds the PTT input on the SDR switch in transmit mode.

The LEDs indicate when the radio’s PTT line is active (red), when the TX INH is active (yellow) and when the preamp is in receive mode (green). The transmit and inhibit LEDs are operated directly from GPIO pins by the software but the preamp LED is operated by the relay which supplies power to the preamp in receive mode providing a positive indication that power is actually being sent to the preamp.

There are provisions for two switches. One switch can turn the preamp on regardless of the radio’s transmit status or force it to be always off regardless of the radio’s status. The other switch can be used to disable the Yaesu’s transmit inhibit line. If being used with a radio without the TX inhibit capability there is no need to add SW1. If a jumper is placed across the header for SW1, however the LED will operate.

Here’s what the printed circuit board layout looks like:

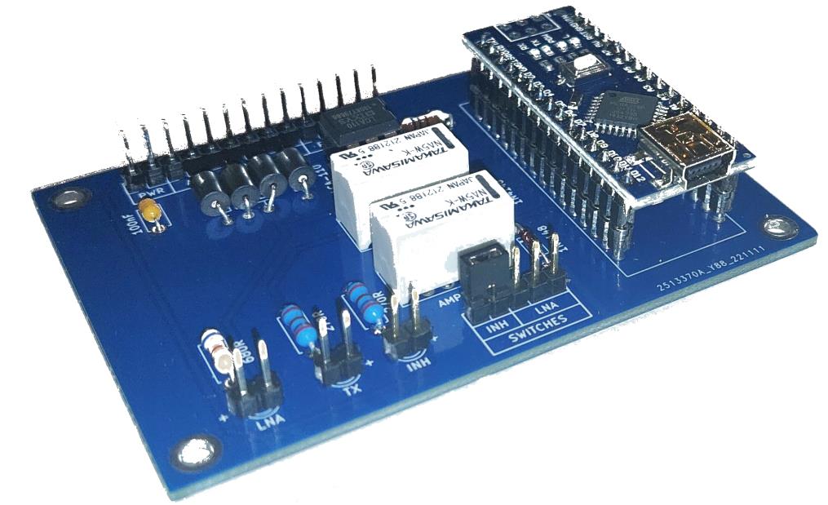
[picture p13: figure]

- Page 8 -

And here’s the assembled board:

Notice, there’s a jumper plug on the connections for the inhibit disable switch. For the FT-891 version, I don’t want to be able to disable it.

SDR Enable/Disable Switch

If using an SDR switcher, you can also install a switch to enable or disable it as shown on the picture below. All that is needed is a SPST toggle switch that grounds the SDR switcher’s PTT input to disable it.

Oops!

There are a couple of errors on the original Version 1.4 PCBs (both are corrected in the Gerber files and in the PCB layout picture above).

- There is a silkscreen label on the back side of the PCB that says ‘Preamp Switch’; ignore it!
- The ‘+’ indication for the INH LED is on the wrong pin.

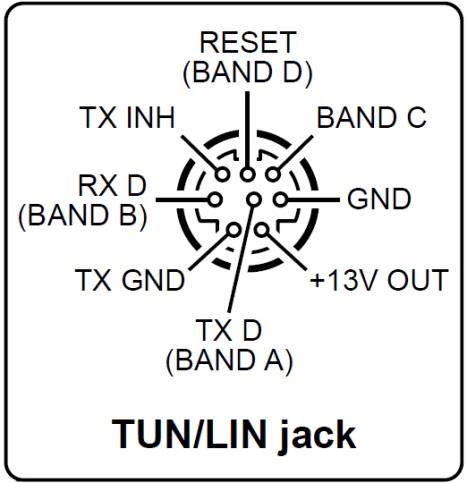
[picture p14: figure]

- Page 9 -

Yaesu FT-891 Connections

This shows the signals present on the FT-891 TUN/LIN mini-DIN jack, which is connected to the sequencer:

Only the GND, TX GND, TX INH and possibly the +13V OUT pins are used by the sequencer.

Icom IC-9700 Connections

The Icom uses a large size 8 pin DIN connector for the external connections:

The full description of the pinout can be found on page 94 the IC-9700 Basic Operating Manual. (https://www.icomjapan.com/support/manual/2156/) The DIN Cable I used to make the connection came from Amazon. (https://www.amazon.com/dp/B0794WSGN9?ref=ppx_yo2_dt_b_product_details&th=1)

- Page 10 -

The following table gives the pin usage and color codes in the cable I used to connect the radio to the sequencer:

Pin | Color | IC-9700 Nomenclature
1 | White | RTTY Keying
2 | Yellow | Ground
3 | Blue | PTT Ground
4 | Green | Modulator input
5 | Brown | AF/IF Output
6 | Pink | Squelch
7 | Red | +13.8V @ 1 Amp
8 | Black | ALC Output

Only pins 2, 3 and possibly 7 are used for the IC-9700 implementation.

I provided both types of DIN jacks on my units connected together so that either sequencer can be used with either radio. If you are building for only one radio, then just use the connection most appropriate for your situation.

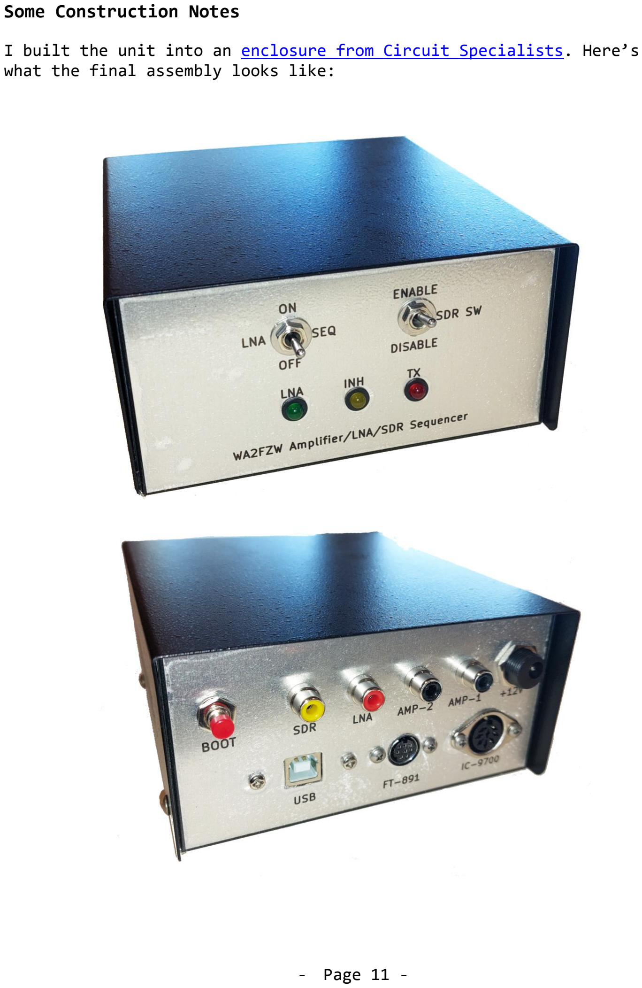
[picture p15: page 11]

- Page 11 -

Some Construction Notes

I built the unit into an enclosure from Circuit Specialists. (https://www.circuitspecialists.com/metal-instrument-enclosure-e-2.html) Here’s what the final assembly looks like:

- Page 12 -

Notice I also added a USB jack so I can reprogram the processor without having to take it apart.

## The Software

GPIO Pin and Other Symbols Defined

The following are the GPIO pin assignments; for the most part, the symbols used match the net names on the schematic:

TX_GROUND | 2 | PTT Indication (interrupt capable)
TX_INH | 4 | Transmit inhibit output to the radio
TX_LED | 5 | Transmit indicator LED
AMP_RELAY | 7 | Operates the linear amplifier relay
LNA_RELAY | 8 | Operates the preamp/SDR switch relay
LNA_OFF | 9 | Preamp always off (bypass) when LOW
LNA_ON | 10 | Preamp always on when LOW

There are several definitions of states for the various GPIO pins, for example:

AMP_ON | LOW | // A LOW on the AMP_RELAY pin keys the linear
AMP_OFF HIGH

There are only five global variables:

txState | Current transmit/receive state
oldTxState | Previous transmit/receive state
lnaForcedOff | true when the switch is in the always off position
lnaForcedOn | true when the switch is in the always on position
txLedState | Used in CheckBlink to toggle the LED state

- Page 13 -

Timing Settings

There are four symbols in the software that define the timing for the sequencer:

AMP_ON_DLY | 50mS Delay between turning the amplifier(s) on and releasing the transmit inhibit line (FT-891 only).
AMP_OFF_DLY | 50mS Delay between turning the amplifier(s) off and returning the preamp and SDR switch to receive mode.
LNA_ON_DLY | 25mS Delay time between switching the preamp and SDR switch to transmit mode and keying the amplifier.
LNA_OFF_DLY | 100mS Currently not used

The values shown are those currently set in the software. The values may be adjusted to suit your needs based on the specifications of your particular equipment and the equipment configuration.

Note, the sequencer is designed for digital mode operations. It can be used for SSB operations provided you use manual PTT (not VOX) and pause slightly between keying the radio and speaking. Using it for CW operation should only be done if the radio is put into transmit manually before operating the CW key; in other words don’t try using break-in modes (I fried a $250 LNA that way)!

Digital Mode Transmit Inhibit Workaround

As mentioned in the Introduction, the fact that the Yaesu FT-891 has the transmit inhibit capability makes things very simple when the sequencer is being used with that radio. But if you are working digital modes using WSJT-X (https://physics.princeton.edu/pulsar/k1jt/wsjtx.html) with a radio that doesn’t have the transmit inhibit capability there is an alternate approach.

- Page 14 -

Under the Settings menu - Advanced tab in WSJT-X, there is a setting for “Tx delay”. The default setting for this is 0.2 seconds and what it does is delay the actual start of the transmitted output for that amount of time after the radio is keyed. 0.2 seconds is plenty of time for the preamp and amplifier to switch modes before any power is transmitted.

The IC-9700 has a menu setting for TX delay which can also be used for other modes.

Overall Functionality

The software is pretty trivial. The setup function sets up all the GPIO pins used and sets them to the proper initial states. Note that there is a specific order in which those are handled that should prevent accidently hitting the preamp with any power before the setup is complete.

At the end of the setup function is a call to the TestLEDs function which is normally commented out. If the function call is un-commented, that function will cycle through all the possible states at 2 second intervals, which allows one to test the operation of the device. It must be connected to the radio or another source of 12V power in order for the preamp LED to light or for power to be provided to the preamp.

The loop function really only does two things; it first calls the SwitchPreamp function which may or may not switch the preamp and SDR switch into receive mode. I’ll explain that function in more detail momentarily.

Next, the loop function looks for changes in the transmit/receive state of the radio and if the state has changed, executes the appropriate sequence of operations to initiate the state change.

The SetTransmit and SetReceive functions perform the state change operations by turning things on or off with the appropriate delays between operations.

The TxInterrupt function is executed via a hardware interrupt anytime the transmit/receive state of the radio changes and simply sets the txState variable as appropriate.

- Page 15 -

The SwitchPreamp Function

This function perhaps deserves a bit more explanation than the other functions. It takes one argument which is the new preamp state and SDR switch requested (LNA_RX or LNA_TX).

When the argument is LNA_TX, the preamp and SDR switch will always be put into transmit (bypass) mode unless the LNA switch (SW2) is in the ‘Always On’ position. If the switch is in the ‘Always On’ position, both the preamp and SDR switch will remain in receive mode (BE VERY CAREFUL).

However, if the argument is LNA_RX, the preamp and SDR switch will only be switched into receive (active) mode if the preamp enable switch is in the ‘SEQ’ position and the PTT is not currently active (TX_OFF).

## Some Operational Notes

Preamp Overload Protection

Both my preamps contain circuitry to protect them from strong nearby signals (in-band or out-of-band). If you use a preamp without such protection, it is important that the enable/disable switch be used to put yours into bypass mode before using a different nearby transmitter and/or antenna. I do this even though my preamp has the protection circuit.

There are front-end protection gimmicks available from DxEngineering, (https://www.dxengineering.com/parts/dxe-rg5000hd?seid=dxese1) and cheaper ones on eBay.

LED Indications

Green LED – On indicates power is being supplied to the preamp.

Yellow LED – On indicates the transmit inhibit is on (FT-891 only)

Red LED – On indicates the radio’s PTT is active. Flashing is a warning that the preamp switch is in the ‘Always On’ mode and transmitting could damage the preamp. This feature is primarily for the IC-9700 where in satellite mode, you are transmitting on one band and receiving on a different band; each band on the IC-9700 has its own antenna feed.

- Page 16 -

Note that putting the preamp switch into the ‘Always On’ position will also put the SDR switch into permanent receive mode and transmitting could also destroy the SDR. Whenever the preamp switch is in ‘Always On’ you should ‘Disable’ the SDR switcher.

SDR Enable/Disable Switch

If you are using an SDR switcher and have installed the switch to disable the SDR switch as described above it is best to disable the SDR when not actually using it.

There are several such switchers available. The one I am using came from Paul (N2EME) and is kind of unique in that it allows one to listen on the radio and SDR simultaneously. It uses a splitter to achieve that. In this arrangement, when not actually using the SDR it is best to disable the switcher as the splitter causes a 3dB loss in the system. When this switcher is disabled, the radio is connected directly to the antenna with negligible insertion loss.

Another good switcher is available from Amazon. (https://www.amazon.com/dp/B08L4YSVJG?psc=1&ref=ppx_yo2ov_dt_b_product_details) This one doesn’t allow simultaneous reception on the transceiver and SDR however. When the SDR switch is in the enabled position, you receive on the SDR; when disabled, you receive on the radio. This switcher has a very low insertion loss and no problems with SWR.

I recommend avoiding the use of the MFJ switcher as it has a 3dB insertion loss built in somehow.

## Suggestion Box

I welcome any suggestions for further improvements. Please feel free to email me at WA2FZW@ARRL.net.

- Page 17 -

## Bill of Materials

Here is a list of the parts you will need and in many cases, links to where you can get the less common parts.

There are hyperlinks to Mouser Electronics for some of the parts. Mouser has implemented a Captcha-like guard against robots. Thus, you can’t simply click on the links, but if you copy the links and paste them into your browser they work (at least they did when I wrote this).

R1, R4 | 270R 1/4W
R2, R3 | 680R 1/4W
FB1 – FB4 | Ferrite bead | The ones I used are no longer available. Pretty much anything will work.
U1 | LCA-110 SSR | 6-pin DIP package; available from Mouser (https://www.mouser.com/ProductDetail/IXYS-Integrated-Circuits/LCA110?qs=AN9n7QNm0jJpFrXJ0Ydzyw%3D%3D) and other common suppliers
U2 | Arduino Nano | I used clones which are much cheaper than genuine Arduinos.
D1, D2, D5 | General purpose LEDs – 20mA | Pick whatever colors you like. I used red, yellow and green.
SW1 | SPST toggle switch | The switches themselves are not on the PCB, but rather mounted on the enclosure. SW1 is connected via a 2-pin male header. SW2 is connected via a 3-pin male header. The PCB is designed such that a single 5-pin header can be used.
SW2 | SPDT center off toggle switch
SW3 | SPST Pushbutton | Reboot switch mounted on the rear panel and connected to the PCB via a 2-pin header
SW4 | SPST Switch | Not shown on the schematic, but can be installed to ground the SDR switch PTT to place it in constant transmit mode.

- Page 18 -
K1,K2 | Fujitsu NA5W-K DPDT relay | Available from Jameco (https://www.jameco.com/z/NA5W-K-Fujitsu-5-Volt-178-Ohm-Double-Pole-Double-Throw-Relay_2202360.html)
J1, J3 | 3-pin male header | The PCB is designed such that a single 14-pin header can be used (includes the 2-pin header for SW3).
J2, J4, J5 | 2-pin male header
FT-891 Connection | mini-DIN female receptacle | CUI Devices MD-80PL100 (https://www.mouser.com/ProductDetail/490-MD-80PL100) – Available from Mouser. Only needed for the FT-891 implementation.
IC-9700 Connection | 8-pin large female DIN receptacle | Available from Jameco. (https://www.jameco.com/z/SD-80SN-JVP-Jameco-ValuePro-Standard-DIN-Socket-Female-8-Pin-Panel-Mount_15861.html) Only needed for the Icom version.
Amplifier, LNA, SDR Switch, etc. Connections | RCA and/or coaxial female receptacles | However many you need to connect all your equipment. Or use whatever you like as connectors for the amplifier, preamp, SDR switch and power connectors.
Enclosure | | I used one from Circuit Specialists; (https://www.circuitspecialists.com/metal-instrument-enclosure-e-2.html) 5.9” x 5.1” x 2.6”.

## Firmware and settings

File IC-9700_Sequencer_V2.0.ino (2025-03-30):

/*
 *	"IC-9700 Sequencer" Version 2.0 - John M. Price (WA2FZW) 02/01/2025
 *
 *		This program was originally designed to run a sequencer for the Yaesu FT-891.
 *		Subsequent versions of the hardware and software were modified to also work with
 *		my Icom FT-9700 on multiple bands.
 *
 *
 *	Modified 11/30/2021 - Version 1.2
 *
 *		The original design didn't work correctly with my Icom IC-9700 when operating
 *		in satellite mode. In satellite mode the radio operates in a full duplex cross-band
 *		mode on the 70cm and 2 meter bands. When transmitting on 70cm, the 2 meter preamp
 *		was being disabled. Since it is important to be able to hear one's self on the
 *		satellites, this was undesirable.
 *
 *		The solution was to modify the preamp enable switch to add a position to force it
 *		to remain on regardless of the TX/RX status of the radio. This also required some
 *		minor changes to the software.
 *
 *		When the preamp for one band is forced on and the radio is in receive mode, the
 *		transmit LED for that band blinks rapidly to warn the operator that transmitting
 *		on that band will probably destroy the preamp.
 *
 *
 *	Modified 12/28/2021 - Version 1.3
 *
 *		Made some slight hardware changes to further simplify the operation with radios other
 *		than the FT-891. One change was to eliminate using separate GPIO pins to turn the
 *		FT-891 transmit inhibit on and to light the associated LED. Both are now operated
 *		from the same GPIO pin.
 *
 *
 *	Modified 11/03/2022 - Version 1.4
 *
 *		Hardware changes to allow keying of 2 amplifiers via K1 (2 meter and 432 on my
 *		IC-9700). Also changed the hardware so that in addition to controlling the LNA,
 *		K2 now switches the LNA and provides a PTT indication to an SDR switch.
 *
 *		Other than I changed the names of some of the symbols, there are no major changes
 *		in the code.
 *
 *
 *	Modified 12/01/2022 - Version 1.5
 *
 *		The hardware and software are both modified to support 2 band operation for the
 *		Icom IC-9700 and support for the Yaesu FT-891 is eliminated.
 *
 *		This version adds the capability to control 2 amplifiers, 2 preamps and 2 SDR
 *		switches for 2 different bands on the IC-9700, and drops the transmit inhibit
 *		capability that was for the FT-891 only.
 *
 *
 *	Modified 02/01/2025 - Version 2.0
 *
 *		The hardware was redesigned to add the capability to trigger the sequencer via
 *		a RTS signal provided over a USB to TTL converter. For digital modes using WSJT-X,
 *		this allows the sequencer to switch the LNA and SDR (if being used) followed by
 *		keying the amplifier and finally keying the radio itself. This allows us to have
 *		the same safety factor as the original design had using the transmit inhibit feature
 *		of the Yaesu FT-891.
 *
 *		For SSB operation where the radio is keyed via the microphone PTT, the original
 *		sequencing is retained. DO NOT try to use VOX keying or break-in CW. A foot switch
 *		can be used in parallel with the RTS signal for safe SSB or CW operation.
 *
 *		An Arduino Nano runs the unit.
 */

#include <Arduino.h>						// General Arduino definitions


/*
 *	Currently, there are 2 'DEBUG' levels. Setting 'DEBUG' to '1' enables status
 *	messages to be sent to the serial monitor. Setting it to '2' causes the
 *	sequence timings to be exaggerated to make the switching sequences easier to
 *	monitor with meters and/or scopes.
 */

#define	DEBUG	1


/*
 *	Define the GPIO pins used for various things.
 */

#define	PTT		    2					// PTT Indication (interrupt capable)
#define	RTS		    3					// RTS Indication (interrupt capable)
#define	TX1_LED		4					// Band 1 transmit indicator LED
#define	TX2_LED		5					// Band 2 transmit indicator LED
#define	AMP_RELAY	7					// Keys the amplifiers
#define	LNA1_RELAY	8					// Operates the band 1 preamp and SDR switch
#define	LNA2_RELAY	9					// Operates the band 2 preamp and SDR switch
#define	TX_KEY	   13					// Keys the radio when sequencer triggered via RTS
#define	LNA1_OFF   A0					// Preamp for band 1 always off (bypass) when LOW
#define LNA1_ON    A1					// Preamp for band 1 always on (RX mode) when LOW
#define	LNA2_OFF   A2					// Preamp for band 2 always off (bypass) when LOW
#define LNA2_ON    A3					// Preamp for band 2 always on (RX mode) when LOW


/*
 *	There are 2 TX LEDs and one might ask why. Whenever one of the LNAs is set to
 *	the always on condition, we blink the TX led associated with that LNA as a 
 *	warning to the operator that if they transmit on that band, they're going to
 *	turn the LNA into smoke!
 */

/*
 *	These symbols are used for the various functions that turn things on and off
 *	to indicate which band(s) the operation is for.
 */

 #define NO_BAND	0						// Neither band
 #define BAND_1		1						// Operation applies to band 1
 #define BAND_2		2						// Operation applies to band 2
 #define BOTH_BANDS 3						// Operation applies to both bands


/*
 *	These define the HIGH/LOW conditions in more meaningful terms:
 */

#define	LED_ON			 LOW				// Turn the transmit (red) LEDs on
#define	LED_OFF			HIGH				// Turn the transmit (red) LEDs off

#define	AMP_ON			 LOW				// Go LOW to key the amplifiers
#define	AMP_OFF			HIGH

#define	LNA_RX			HIGH				// Go LOW to put the LNAs in receive mode
#define	LNA_TX			 LOW				// LOW also triggers the SDR switchs

#define	TX_OFF			HIGH				// When PTT is HIGH, transmitter is off
#define	TX_ON			 LOW				// When PTT is LOW, transmitter is on

#define	RTS_ACTIVE		 LOW				// The RTS and PTT pins are active
#define	PTT_ACTIVE		 LOW				// when they show a LOW indication


/*
 *	These symbols control the delay times between when we see the transmitter keyed
 *	and when we turn the amplifier and preamp on or off. I measured the on/off times for
 *	the preamp; it takes about 5mS to switch from receive to transmit and about 50mS
 *	to switch back to receive. We'll set the times considerably higher just to be sure.
 *
 *	If the DEBUG level is 2 or higher, the times are lengthened to facilitate checking
 *	the operation with a meter and/or a scope.
 */

#if ( DEBUG >= 2 )

#define	LNA_ON_DLY		3000				// Wait time after switching LNA to TX
#define	PTT_ON_DELAY	3000				// Wait time after switching amp to TX
#define	PTT_OFF_DELAY	  10				// Wait time between RTS inactive and PTT off
#define	AMP_OFF_DLY		3000				// Wait time after switching amp to RX

#else

#define	LNA_ON_DLY		25					// Wait time after switching LNA to TX
#define	PTT_ON_DELAY	50					// Wait time after switching amp to TX
#define	PTT_OFF_DELAY	10					// Wait time between RTS inactive and PTT off
#define	AMP_OFF_DLY		50					// Wait time after switching amp to RX

#endif


/*
 *	These are used to determine when the TX/RX state changes:
 */

volatile bool	txState     = TX_OFF;		// Current transmit/receive state
volatile bool	oldTxState  = TX_OFF;		// Previous state

volatile bool	rtsState   	= !RTS_ACTIVE;	// Assume RTS is not active (it could be)
volatile bool	pttState    = !PTT_ACTIVE;	// Assume PTR is not active (it could be)

		 bool	lna_1_ForcedOff;			// Preamp #1 always off if true
		 bool	lna_1_ForcedOn;				// Preamp #1 is always on if true
		 bool	lna_2_ForcedOff;			// Preamp #2 always off if true
		 bool	lna_2_ForcedOn;				// Preamp #2 is always on if true

		 bool	tx_1_LedState = false;		// Blinking TX1_LED is off
		 bool	tx_2_LedState = false;		// Blinking TX2_LED is off


/*
 *	"setup" initializes all the GPIO pins and the serial port. The serial port isn't
 *	really used except for debugging.
 */

void setup()
{
	Serial.begin ( 115200 );						// Start the serial monitor port


/*
 *	Set up the GPIO pins:
 *
 *	The order of things here is important.
 *
 *	Experimentation has shown that the preamp and amplifier relays will not operate
 *	until they are set as OUTPUT pins, thus the preamp will startup in transmit
 *	(bypass) mode and the amplifier will be off.
 *
 *	Make sure the radio isn't transmitting, unless the operator has it keyed manually.
 */

	pinMode ( TX_KEY, OUTPUT);
	digitalWrite ( TX_KEY, TX_OFF );

	txState = TX_OFF;								// Assume transmitter is off


/*
 *	Make sure the amplifier is off:
 */

	pinMode      ( AMP_RELAY, OUTPUT );				// Amplifier relay
	digitalWrite ( AMP_RELAY, AMP_OFF );			// Amplifiers are off

	pinMode		 ( LNA1_ON,  INPUT_PULLUP );		// Preamp #1 always on switch contact
	pinMode		 ( LNA1_OFF, INPUT_PULLUP );		// Preamp #1 always off switch contact
	pinMode      ( LNA1_RELAY, OUTPUT );			// Preamp/SDR switch #1 relay

	pinMode		 ( LNA2_ON,  INPUT_PULLUP );		// Preamp #2 always on switch contact
	pinMode		 ( LNA2_OFF, INPUT_PULLUP );		// Preamp #2 always off switch contact
	pinMode      ( LNA2_RELAY, OUTPUT );			// Preamp/SDR switch #2 relay


/*
 *	Now we can safely put the preamps into receive mode if they are enabled:
 */

	delay ( AMP_OFF_DLY );							// Time for amp to switch to RX
	SwitchPreamp ( BOTH_BANDS, LNA_RX );			// Put LNAs into RX mode


/*
 *	Setup the LED, RTS and PTT pins, then get the current states of the RTS and PTT
 *	pins. If either is active it will be detected in the loop function and the
 *	appropriate action will be taken to start the appropriate transmit sequence.
 *
 *	Notice, we have NOT enabled the interrupt capability for either of these pins yet
 *	and that the old states are set to !ACTIVE.
 */

	pinMode      ( TX1_LED, OUTPUT );				// Band 1 transmit indicator LED pin
	pinMode      ( TX2_LED, OUTPUT );				// Band 2 transmit indicator LED pin

	pinMode      ( RTS, INPUT_PULLUP );				// USB to TTL converter RTS indicator pin
	pinMode      ( PTT, INPUT_PULLUP );				// Radio PTT indicator pin

	rtsState = digitalRead ( RTS );					// Get current RTS state
	pttState = digitalRead ( PTT );					// And PTT state


/*
 *	Whenever the radio changes state from transmit to receive or vice-versa an
 *	interrupt is generated. The radio can be put into the transmit mode by pressing
 *	the PTT switch on the microphone or via the transmit button on the radio. In
 *	either case an interrupt is generated from the PTT GPIO pin.
 *
 *	When operating on one of the digital modes using WSJT-X (or other programs),
 *	an interrupt is generated from the RTS GPIO pin. A footswitch can also be
 *	installed that mimics RTS keying for SSB or CW operation.
 *
 *	How we handle the sequencing is different depending how the sequencing was
 *	initiated. 
 */

	attachInterrupt	( digitalPinToInterrupt ( RTS ), RTS_ISR, CHANGE );
	attachInterrupt	( digitalPinToInterrupt ( PTT ), PTT_ISR, CHANGE );

	Serial.println ( "WA2FZW - Amplifier/Preamp Sequencer - Version 2.0\n" );

#if	DEBUG

	ShowPinStatus ();					// Display status of control inputs

#endif

//	Test_LNA ();						// Operates the relays in a never ending loop

}										// End of 'setup'


void loop ()
{
	CheckBlink ();								// Need to flash the TX LED?


/*
 *	SwitchPreamp is called every 50 milliseconds to detect whether or not the
 *	position of one of the LNA switches has changed.
 */

	if (( millis () % 50 ) == 0 )
		SwitchPreamp ( BOTH_BANDS, LNA_RX );	// See if either preamp needs to be in RX mode


/*
 *	If either the PTT or RTS line is active, the transmitter should be on if not so already.
 *	If both the PTT and RTS lines are not active, the transmitter should be in receive mode
 *	if not so already. Note the optional footswitch is operated, that is the same as the RTS
 *	being active.
 */

	if (( pttState == PTT_ACTIVE ) || ( rtsState == RTS_ACTIVE ))
		txState = TX_ON;

	if (( pttState != PTT_ACTIVE ) && ( rtsState != RTS_ACTIVE ))
		txState = TX_OFF;


/*
 *	Adding the following two lines of code cured a problem of the sequencer locking up
 *	in transmit mode when the foot switch was operated and released before the receive
 *	to transmit sequence had time to complete. I'm still not exactly sure why this fixed
 *	the problem!
 */

	if (( pttState == PTT_ACTIVE ) && ( rtsState != RTS_ACTIVE ))
		SetReceive ();


/*
 *	There are two ways the PTT can be active; either the radio was keyed manually, or
 *	the PTT was activated at the end of the transmit sequence that was initiated by
 *	the RTS going active.
 *
 *	So, whenever we see the PTT active, we turn the transmit LEDs on.
 */

	if ( digitalRead ( PTT ) == PTT_ACTIVE )
	{
		digitalWrite ( TX1_LED, LED_ON );
		digitalWrite ( TX2_LED, LED_ON );
	}

	else
	{
		digitalWrite ( TX1_LED, LED_OFF );
		digitalWrite ( TX2_LED, LED_OFF );
	}


/*
 *	If the transmitter state changed, we need to figure out how things changed and
 *	take the appropriate action. When going from receive to transmit, the sequence
 *	of switching depends on whether the transmitter was ordered on via the RTS
 *	line or via the PTT line. That will be handled in the SetTransmit function.
 */

	if ( txState != oldTxState )				// Did TX/RX state change?
	{
#if DEBUG

		Serial.print ( "\nTime: " );	Serial.println ( millis ());
		Serial.print ( "pttState = " );	Serial.println ( pttState );
		Serial.print ( "rtsState = " );	Serial.println ( rtsState );

#endif

		if ( txState == TX_ON )					// Now transmitting?
			SetTransmit ();						// Yes, run transmit setup sequence

		else									// If receiving
			SetReceive ();						// Run the receive setup sequence
	}
}												// End of loop function


/*
 *	SetTransmit puts the preamps into transmit mode then after LNA_ON_DLY milliseconds
 *	turns on the selected amplifier. The preamp/SDR switch LED operates from the associated
 *	preamp relay, so its state is handled automagically.
 *
 *	If the transmitter was ordered on via the RTS line, we also key the radio via the
 *	TX_KEY GPIO pin, which activates the radio's PTT line via K4 on the schematic. Note
 *	that this will cause an interrupt that the PTT_ISR function will see. It will be
 *	ignored it RTS is active.
 */

void SetTransmit ()
{
	SwitchPreamp ( BOTH_BANDS, LNA_TX );		// Switch the preamps and SDR switches to TX mode

	if ( DEBUG )
	{
		Serial.print ( "LNAs in TX: " );	Serial.println ( millis ());
	}

	delay ( LNA_ON_DLY );						// Wait for the preamp(s) to actually switch

	digitalWrite ( AMP_RELAY, AMP_ON );			// Then turn on the amplifier(s)

	if ( DEBUG )
	{
		Serial.print ( "Amp On " );			Serial.println ( millis ());
	}


/*
 *	If the RTS is active, we key the radio's PTT line, but note that we do not mark the PTT
 *	as being active. Doing so caused a lockup where the PTT was never being released when the
 *	RTS went inactive. Note also that PTT interrupts are ignored in the PTT_ISR function when
 *	RTS is active.
 */

	if ( rtsState == RTS_ACTIVE )				// Transmit commanded via the RTS?
	{
		delay ( PTT_ON_DELAY );					// Yes, wait for amplifier to switch to TX
		digitalWrite ( TX_KEY, TX_ON );			// Then key the radio

		if ( DEBUG )
		{
			Serial.print ( "PTT On " );		Serial.println ( millis ());
		}
	}

	oldTxState = txState = TX_ON;				// Transmitter is on
}												// End of SetTransmit


/*
 *	SetReceive also becomes a bit trickier in version 2.0 because that radio can
 *	now be transmitting because the RTS line was keyed by one of the digital programs
 *	or the optional footswitch or manually via the PTT line.
 *
 *	First thing we will do is to check if the RTS line is active. If it is active,
 *	we simply set the transmit state to on and return.
 *
 *	If RTS is inactive, we will try to put the radio into receive mode by dropping the
 *	TX_KEY line which will drop the PTT line unless the radio was also manually keyed.
 *	If that is the case, we don't want to switch the amplifier, LNA and SDR switch to
 *	receive mode.
 */

void SetReceive ()
{
	if ( digitalRead ( RTS ) == RTS_ACTIVE )	// If RTS is still on
	{
		txState = TX_ON;						// Then transmitter is assumed to be on
		return;									// Don't do anything
	}


/*
 *	RTS is not active, but may have been. If it was active, PTT might be active because
 *	we turned it on via K4, but it may have been on because the transmitter had been
 *	keyed manually.
 *
 *	We check to see if PTT is on and if so, we turn it off and wait up to PTT_OFF_DELAY
 *	milliseconds to see if it gors inactive. If PTT is still on after the delay, we
 *	assume that the transmitter is still manually keyed, so we need to show the 'txState'
 *	as ACTIVE and we return.
 */
 

	if ( digitalRead ( PTT ) == PTT_ACTIVE )			// Could be manual keying or K4
		for ( int i = 0; i < PTT_OFF_DELAY; i++ )
		{
			delay ( 1 );								// Wait a millisecond
			digitalWrite ( TX_KEY, TX_OFF );			// Try to put the radio back in receive mode
			if ( digitalRead ( PTT ) != PTT_ACTIVE )	// If PTT is inactive
				break;									// All is good!
		}

	if ( digitalRead ( PTT ) == PTT_ACTIVE )	// Check it again; if active
	{
		txState = TX_ON;						// the transmitter is assumed to be on
		return;									// manually, so don't do anything
	}

	if ( DEBUG )
	{
		Serial.print ( "PTT Off " );		Serial.println ( millis ());
	}

	digitalWrite ( TX1_LED, LED_OFF );
	digitalWrite ( TX2_LED, LED_OFF );

	digitalWrite ( AMP_RELAY, AMP_OFF );		// Then turn the amplifier off
	delay ( AMP_OFF_DLY );						// Wait for it to actually switch

	if ( DEBUG )
	{
		Serial.print ( "Amp Off " );		Serial.println ( millis ());
	}

	delay ( LNA_ON_DLY );						// Wait for it to actually switch

	SwitchPreamp ( BOTH_BANDS, LNA_RX );		// Switch the preamps to RX mode if appropriate

	if ( DEBUG )
	{
		Serial.print ( "LNAs in RX: " );	Serial.println ( millis ());
	}

	oldTxState = txState = TX_OFF;				// The transmitter is off
}												// End of SetRecive


/*
 *	CheckBlink looks to see if the 'txState' is off (receive mode) and one or both of
 *	the LNAs are in the forced on mode. If so, we flash the associated transmit LED every
 *	tenth of a second as a warning to the operator.
 *
 *	As noted in the documentation, one must be extremly cautious putting the preamp and
 *	into the permanent on mode. The capability was added do that when using my IC-9700 in
 *	satellite mode and transmitting on 70cm and receiving on 2 meters, the 2 meter preamp
 *	would still be on when transmitting on 70cm (or vice-versa).
 */

void CheckBlink ()
{
	if (( millis() % 100 ) != 0 )						// Tenth of a second mark?
		return;											// Nothing to do yet


/*
 *	Check preamp #1:
 */

	if (( txState == TX_OFF ) && lna_1_ForcedOn )
	{
		tx_1_LedState = !tx_1_LedState;
		digitalWrite ( TX1_LED, tx_1_LedState );	// Blink the LED
	}

	else if ( txState == TX_OFF )					// Not transmitting and preamp not
		digitalWrite ( TX1_LED, LED_OFF );			// forced on - LED off


/*
 *	Check preamp #2:
 */

	if (( txState == TX_OFF ) && lna_2_ForcedOn )
	{
		tx_2_LedState = !tx_2_LedState;
		digitalWrite ( TX2_LED, tx_2_LedState );	// Blink the LED
	}

	else if ( txState == TX_OFF )					// Not transmitting and preamp not
		digitalWrite ( TX2_LED, LED_OFF );			// forced on - LED off

	delay ( 2 );									// Force clock ahead a couple of ticks						
}													// End of CheckBlink


/*
 *	PTT_ISR is called via an interrupt whenever the PTT pin changes state, and
 *	RTS_ISR is called via an interrupt whenever the RTS pin changes state.
 *
 *	All we do is set the current state of the pins. The loop logic will figure out
 *	what to do with the information.
 *
 *	Note that when the sequence is triggered by the RTS signal, we will get a PTT
 *	interrupt when we key the radio via the TX_KEY GPIO pin; it will be ignored.
 */

void PTT_ISR ()
{
	if ( rtsState == RTS_ACTIVE )
		return;

	pttState = digitalRead ( PTT );
}

void RTS_ISR ()
{
	rtsState = digitalRead ( RTS );
}


/*
 *	SwitchPreamp turns the preamp on or off based on the argument and the state of
 *	the preamp switch.
 *
 *	Modified in Version 1.2 to allow the preamp to be forced into the always off mode
 *	or always on regardless of the TX/RX state of the radio.
 *
 *	If both the LNA_ON and LNA_OFF pins are in a high state, the preamp is turned
 *	on or off based on the TX/RX status of the radio.
 *
 *	If the LNA_ON pin is low, the preamp is turned on regardless of the TX/RX state
 *	of the radio.
 *
 *	If the LNA_OFF pin is low, the preamp is turned off regardless of the TX/RX state of
 *	the radio.
 *
 *	In Version 1.4, the LNA relay also operates an SDR switch. It can be disabled
 *	separately by turning its power off or operating the bypass switch on the unit.
 *
 *	Modified in Version 1.5 to operate either one of 2 LNAs or both. For now, the code
 *	is essentially repeated twice; once for each preamp/SDR.
 */

void SwitchPreamp ( uint8_t whichBand, bool newState )
{
	if ( whichBand && BAND_1 )					// Band 1 request (or maybe both)?
	{


/*
 *	First see if the preamp switch is in the always on mode. That is incicated by a LOW
 *	on the LNA_ON pin. If this is the case, we turn it on and return.
 */

		lna_1_ForcedOn = !digitalRead ( LNA1_ON );		// Forced on if LOW

		if ( lna_1_ForcedOn )
			digitalWrite ( LNA1_RELAY, LNA_RX );		// Switch the preamp to receive mode


/*
 *	Next see if the switch says the preamp should remain off. This is indicated by a
 *	LOW condition on the LNA_OFF pin.
 */

		lna_1_ForcedOff = !digitalRead ( LNA1_OFF );	// See if the preamp is disabled

		if ( lna_1_ForcedOff )
			digitalWrite ( LNA1_RELAY, LNA_TX );		// Switch the preamp to transmit mode


/*
 *	If we get here, the preamp status depends entirely on the TX/RX state of the radio.
 *	If the requested state is receive mode and we aren't transmitting, then we put the
 *	preamp in to receive (on) mode. If the radio is transmitting or the requested mode
 *	is transmit, then we put the preamp into transmit (bypass) mode.
 */

		if ( !lna_1_ForcedOn && !lna_1_ForcedOff )		// If in sequenced mode
		{
			if (( newState == LNA_RX ) && ( txState == TX_OFF ))
				digitalWrite ( LNA1_RELAY, LNA_RX );	// Switch the preamp to receive mode

			else
				digitalWrite ( LNA1_RELAY, LNA_TX );	// Switch the preamp to transmit mode
		}
	}
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

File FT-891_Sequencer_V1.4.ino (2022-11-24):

/*
 *	"FT-891 Sequencer" Version 1.4 - John M. Price (WA2FZW) 11/03/2022
 *
 *		This program runs the FT-891 sequencer module that I designed. The purpose
 *		of the module is to switch an antenna mounted meter preamp from receive mode
 *		to transmit mode, then key the linear amplifier before the FT-891 actually
 *		starts transmitting. When the radio goes from transmit to receive, the process is
 *		reversed.
 *
 *		The PCB uses relays to provide power (or remove it) from the preamp and to key the
 *		amplifier.
 *
 *		The key to the operation is the fact that the FT-891 has a "TX Inhibit" input.
 *		When +5V is applied to that input, it prevents the radio from transmitting
 *		regardless of the state of the PTT line.
 *
 *		An Arduino Nano runs the unit.
 *
 *
 *	Modified 11/30/2021 - Version 1.2
 *
 *		The original design didn't work correctly with my Icom IC-9700 when operating
 *		in satellite mode. In satellite mode the radio operates in a full duplex cross-band
 *		mode on the 70cm and 2 meter bands. When transmitting on 70cm, the 2 meter preamp
 *		was being disabled. Since it is important to be able to hear one's self on the
 *		satellites, this was undesirable.
 *
 *		The solution was to modify the preamp enable switch to add a position to force it
 *		to remain on regardless of the TX/RX status of the radio. This also required some
 *		minor changes to the software.
 *
 *		When the preamp is forced on and the radio is in receive mode, the transmit LED
 *		blink rapidly to warn the operator that transmitting in that mode might damage
 *		the preamp if transmitting on the same antenna connection.
 *
 *
 *	Modified 12/28/2021 - Version 1.3
 *
 *		Made some slight hardware changes to further simplify the operation with radios other
 *		than the FT-891. One change was to eliminate using separate GPIO pins to turn the
 *		FT-891 transmit inhibit on and to light the associated LED. Both are now operated
 *		from the same GPIO pin.
 *
 *
 *	Modified 11/03/2022 - Version 1.4
 *
 *		Hardware changes to allow keying of 2 amplifiers via K1 (2 meter and 432 on the
 *		IC-9700). Also changed the hardware so that in addition to controlling the LNA,
 *		K2 now switches the LNA and provides a PTT indication to an SDR switch for the
 *		FT-891.
 *
 *		Other than I changed the names of some of the symbols, there are no major changes
 *		in the code.
 */

#include <Arduino.h>						// General Arduino definitions


/*
 *	Define the GPIO pins used for various things.
 */

#define	TX_GROUND	    2					// PTT Indication (interrupt capable)
#define	TX_INH			4					// Transmit inhibit output to the radio
#define	TX_LED			5					// Transmit indicator LED
#define	AMP_RELAY		7					// Keys the amplifiers
#define	LNA_RELAY		8					// Operates the preamp and SDR switch
#define	LNA_OFF			9					// Preamp always off (bypass) when LOW
#define LNA_ON		   10					// Preamp always on (RX mode) when LOW


/*
 *	These define the HIGH/LOW conditions in more meaningful terms:
 */

#define	LED_ON			 LOW				// Turn the transmit (red) LED on
#define	LED_OFF			HIGH				// Turn the transmit (red) LED off

#define	PTT_ON			 LOW				// When TX_GROUND (aka PTT) is LOW we're transmitting
#define	PTT_OFF			HIGH				// Receiving

#define	AMP_ON			 LOW				// Go LOW to key the amplifiers
#define	AMP_OFF			HIGH

#define	LNA_RX			HIGH				// Go LOW to put the LNA in receive mode
#define	LNA_TX			 LOW				// LOW also triggers the SDR switch

#define	INH_ON			HIGH				// TX_INH goes high to stop transmitting
#define	INH_OFF			 LOW				// on the FT-891 only (N/A for the IC-9700)

#define	TX_OFF			HIGH				// When "TX_GROUND" is HIGH, transmitter is off
#define	TX_ON			 LOW				// When "TX_GROUND" is LOW, transmitter is on


/*
 *	These symbols control the delay times between when we see the transmitter keyed
 *	and when we turn the amplifier and preamp on or off. I measured the on/off times for
 *	the preamp; it takes about 5mS to switch from receive to transmit and about 50mS
 *	to switch back to receive. We'll set the times considerably higher just to be sure.
 *
 *	I haven't measured the switching time for the amp, but it really doesn't matter.
 */

#define	AMP_ON_DLY		 50					// 50 milliseconds
#define	AMP_OFF_DLY		 50					// 50 milliseconds

#define	LNA_ON_DLY		 25					// 25 milliseconds
#define	LNA_OFF_DLY		100					// 100 milliseconds (currently not used)


/*
 *	These are used to determine when the TX/RX state changes:
 */

volatile bool txState     = TX_OFF;			// Current transmit/receive state
volatile bool oldTxState  = TX_OFF;			// Previous state

		 bool lnaForcedOff;					// Preamp always off if true
		 bool lnaForcedOn;					// Preamp is always on if true

		 bool txLedState = false;			// Blinking TX LED is off


/*
 *	"setup" initializes all the GPIO pins and the serial port. The serial port isn't
 *	really used except for debugging.
 */

void setup()
{
	Serial.begin ( 115200 );						// Start the serial monitor port


/*
 *	Set up the GPIO pins:
 *
 *	The order of things here is important. The first thing we do is to turn the TX
 *	inhibit line on (applies to the FT-891 only). Should the transmitter happen to
 *	be keyed when the program starts, this will prevent the transmitter from producing
 *	any output power until everything else is set up.
 *
 *	Experimentation has shown that the preamp and amplifier relays will not operate
 *	until they are set as "OUTPUT" pins, thus the preamp will startup in transmit
 *	(bypass) mode and the amplifier will be off.
 */

	pinMode		 ( TX_INH, OUTPUT );			// Actual inhibit signal and associated LED
	digitalWrite ( TX_INH, INH_ON );			// are on


/*
 *	Next, make sure the amplifier is off:
 */

	pinMode      ( AMP_RELAY, OUTPUT );			// Amplifier relay
	digitalWrite ( AMP_RELAY, AMP_OFF );		// Amplifiers are off

	pinMode		 ( LNA_ON,  INPUT_PULLUP );		// Preamp always on switch contact
	pinMode		 ( LNA_OFF, INPUT_PULLUP );		// Preamp always off switch contact
	pinMode      ( LNA_RELAY, OUTPUT );			// Preamp/SDR switch relay


/*
 *	Now we can safely put the preamp into receive mode if it is enabled:
 */

	SwitchPreamp ( LNA_RX );


/*
 *	We don't really know the state of the PTT signal, so we will check it. Based on
 *	its current state, we set the values of "txState" and "oldTxState" and turn the
 *	TX LED on or off as appropriate. Remember, the TX inhibit is still on, so the
 *	radio cannot actually produce power (FT-891 only).
 */

	pinMode      ( TX_GROUND, INPUT_PULLUP );			// Radio PTT indicator pin
	oldTxState = txState = digitalRead ( TX_GROUND );	// Read it and set state variables

	pinMode      ( TX_LED, OUTPUT );					// Transmit indicator LED pin

	if ( txState == TX_ON )								// Is the PTT active?
		digitalWrite ( TX_LED, LED_ON );				// Yes, turn the LED on

	else												// Otherwise
		digitalWrite ( TX_LED, LED_OFF );				// Yes, turn the LED off
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
